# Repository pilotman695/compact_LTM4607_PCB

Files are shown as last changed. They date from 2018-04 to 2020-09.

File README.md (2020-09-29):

# compact_LTM4607_PCB
A compact, 98% efficient, non-isolated DC-DC converter board based around the LTM4607

Input: 4.5-36V

Output: 0.8-24V, 5A (boost mode), 10A (buck mode)

## Version 1
Stand-off mounting, solderable wire connections

## Version 2
Card-edge style, compacted

Assembly tutorial: [https://www.youtube.com/watch?v=_QmpLCoHiIg](https://www.youtube.com/watch?v=_QmpLCoHiIg)

## Carrier Board
3 card-edge connectors, hotswapping, reverse polarity protection, switchable output nodes, undervoltage/overvoltage lockout

Input: 12.5-36V

Output: 3.3-24V

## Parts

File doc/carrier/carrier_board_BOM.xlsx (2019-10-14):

Qty | Parts | Value | Device | Package | Description | Manufacturer Part Number | Datasheet | Unit Price | Total
5 | C1, C2, C3, C9, C10 | 100n | C-EUC0603 | C0603 | CAPACITOR, European symbol | CL10F104ZB8NNNC | http://www.samsungsem.com/global/front/downloadcms.do?fileName=C_CL10F104ZB8NNNC.pdf | $0.054 | $0.270
1 | C4 | 1n | C-EUC0402 | C0402 | CAPACITOR, European symbol | GCM155R71H102KA37D | http://psearch.en.murata.com/capacitor/product/GCM155R71H102KA37%23.pdf | $0.140 | $0.140
1 | C5 | 100n | C-EUC0402 | C0402 | CAPACITOR, European symbol | C1005X7R1H104K050BB | https://product.tdk.com/info/en/documents/chara_sheet/C1005X7R1H104K050BB.pdf | $0.180 | $0.180
1 | C6 | 100u | CPOL-USE5-10.5 | E5-10,5 | POLARIZED CAPACITOR, American symbol | EEU-FR1J101 | https://industrial.panasonic.com/cdbs/www-data/pdf/RDF0000/ABA0000C1022.pdf | $0.910 | $0.910
2 | C7, C8 | 100n | C-EUC0805 | C0805 | CAPACITOR, European symbol | CL21F104ZBCNNNC | http://www.samsungsem.com/kr/front/downloadcms.do?fileName=C_CL21F104ZBCNNNC.pdf | $0.140 | $0.280
2 | CON1, CON2 | SM03B-GHS-TB | SM03B-GHS-TB | SM03B-GHS-TB |  | SM03B-GHS-TB(LF)(SN) | http://www.jst-mfg.com/product/pdf/eng/eGH.pdf | $0.690 | $1.380
3 | D1, D2, D3 | 10 | BZT52C10-TP | SOD123 |  | BZT52C10-TP | http://www.mccsemi.com/up_pdf/BZT52C2V4~BZT52C43(500mW)(SOD-123).pdf | $0.310 | $0.930
2 | D4, D5 | SMBJ30CA | SMBJ30CA | DO214AA |  | SMBJ30CA | https://www.littelfuse.com/~/media/electronics/datasheets/tvs_diodes/littelfuse_tvs_diode_smbj_datasheet.pdf.pdf | $0.650 | $1.300
2 | D6, D7 | SD0603S040S0R2 | SD0603S040S0R2 | CHIPLED_0603 | DIODE SCHOTTKY 40V 200MA 0603 | SD0603S040S0R2 | http://datasheets.avx.com/schottky.pdf | $0.660 | $1.320
1 | D8 | MBRS2040LT3G | MBRS2040LT3G | DO214AA | DIODE SCHOTTKY 40V 2A SMB | MBRS2040LT3G | https://www.onsemi.com/pub/Collateral/MBRS2040LT3-D.PDF | $0.530 | $0.530
3 | F1, F2, F3 |  | FUSEHOLDER | 3557-10 |  | 3557-10 | http://www.keyelco.com/product-pdf.cfm?p=14224 | $1.360 | $4.080
3 | F1, F2, F3 | 15A | FUSE | Blade, Miniature (Low Profile) |  | 0891015.NXS | http://www.littelfuse.com/~/media/automotive/datasheets/fuses/passenger-car-and-commercial-vehicle/blade-fuses/littelfuse_lowprofilemini_datasheet.pdf | $0.520 | $1.560
2 | F4, F5 |  | 3557-10 | 3557-10 |  | 3557-10 | http://www.keyelco.com/product-pdf.cfm?p=14224 | $1.360 | $2.720
2 | F4, F5 | 30A | FUSEHOLDER | Blade, Miniature (Low Profile) |  | 0891030.NXS | http://www.littelfuse.com/~/media/automotive/datasheets/fuses/passenger-car-and-commercial-vehicle/blade-fuses/littelfuse_lowprofilemini_datasheet.pdf | $0.520 | $1.040
1 | F6 | 0.5 | FUSE | R1206 |  | ERB-RG0R50V | https://industrial.panasonic.com/cdbs/www-data/pdf/AFA0000/AFA0000C7.pdf | $0.780 | $0.780
1 | JP1 |  | PINHD-2X3 | 2X03 | PIN HEADER | PREC003DAAN-RC | https://s3.amazonaws.com/catalogspreads-pdf/PAGE110-111%20.100%20MALE%20HDR%20ST.pdf | $0.250 | $0.250
1 | JP2 |  | PINHD-2X4 | 2X04 | PIN HEADER | PREC004DAAN-RC | https://s3.amazonaws.com/catalogspreads-pdf/PAGE110-111%20.100%20MALE%20HDR%20ST.pdf | $0.270 | $0.270
1 | JP3 |  | PINHD-1X02_2.54-SMD-90Â° | 1X02SMD/90 | PIN HEADER | TSM-102-01-T-SH | http://suddendocs.samtec.com/catalog_english/tsm.pdf | $0.400 | $0.400
2 | LED1, LED2 |  | LEDCHIPLED_0603 | CHIPLED_0603 | LED | 150060VS55040 | https://katalog.we-online.de/pbs/datasheet/150060VS55040.pdf | $0.240 | $0.480
3 | Q1, Q2, Q3 | SQJ407EP | SQJ407EP | POWERPACK_SO8L_SINGLE |  | SQJ407EP-T1_GE3 | http://www.vishay.com/docs/62806/sqj407ep.pdf | $1.980 | $5.940
4 | Q4, Q5, Q6, Q7 | SI7145DP | SI7145DP | SO-8-POWERPACK |  | SI7145DP-T1-GE3 | http://www.vishay.com/docs/64814/si7145dp.pdf | $3.680 | $14.720
1 | Q8 | BSS123 | BSS123 | SOT23 |  | DMN6075S-7 | https://www.diodes.com/assets/Datasheets/DMN6075S.pdf | $0.610 | $0.610
8 | R1, R2, R7, R8, R13, R14, R35, R36 | 1k | R-US_R0603 | R0603 | RESISTOR, American symbol | RC0603FR-071KL | http://www.yageo.com/documents/recent/PYu-RC_Group_51_RoHS_L_9.pdf | $0.039 | $0.312
2 | R19, R22 | 4.12M | R-US_R0402 | R0402 | RESISTOR, American symbol | CRCW04024M12FKED | http://www.vishay.com/docs/20035/dcrcwe3.pdf | $0.066 | $0.132
2 | R20, R23 | 210k | R-US_R0402 | R0402 | RESISTOR, American symbol | RC0402FR-07232KL | http://www.yageo.com/documents/recent/PYu-RC_Group_51_RoHS_L_9.pdf | $0.027 | $0.054
2 | R21, R24 | 150k | R-US_R0402 | R0402 | RESISTOR, American symbol | RC0402FR-07124KL | http://www.yageo.com/documents/recent/PYu-RC_Group_51_RoHS_L_9.pdf | $0.027 | $0.054
1 | R26 | 255k | R-US_R0402 | R0402 | RESISTOR, American symbol | RC0402FR-07255KL | http://www.yageo.com/documents/recent/PYu-RC_Group_51_RoHS_L_9.pdf | $0.027 | $0.027
2 | R28, R29 | 10k | R-US_R1206 | R0805 | RESISTOR, American symbol | RC0805FR-0710KL | http://www.yageo.com/documents/recent/PYu-RC_Group_51_RoHS_L_9.pdf | $0.069 | $0.138
5 | R3, R9, R15, R25, R27 | 100k | R-US_R0603 | R0603 | RESISTOR, American symbol | AC0603FR-07100KL | http://www.yageo.com/NewPortal/yageodocoutput?fileName=/pdf/R-Chip/PYu-AC_51_RoHS_L_6.pdf | $0.048 | $0.240
2 | R30, R33 | 2k | R-US_R0603 | R0603 | RESISTOR, American symbol | RC0603FR-072KP | http://www.yageo.com/NewPortal/yageodocoutput?fileName=/pdf/R-Chip/PYu-RC_51_RoHS_P_0.pdf | $0.066 | $0.132
2 | R31, R32 | 220 | R-US_R0805 | R0805 | RESISTOR, American symbol | AC0805FR-07220RL | http://www.yageo.com/NewPortal/yageodocoutput?fileName=/pdf/R-Chip/PYu-AC_51_RoHS_L_6.pdf | $0.082 | $0.164
1 | R34 | 1k | R-US_R0805 | R0805 | RESISTOR, American symbol | RC0805FR-071KL | http://www.yageo.com/documents/recent/PYu-RC_Group_51_RoHS_L_9.pdf | $0.069 | $0.069
1 | R37 | 0 | R-US_R0805 | R0805 | RESISTOR, American symbol | RC0603JR-070RL | http://www.yageo.com/documents/recent/PYu-RC_Group_51_RoHS_L_9.pdf | $0.032 | $0.032
3 | R4, R10, R16 | 2.5m | R-US_R2512 | R2512 | RESISTOR, American symbol | TLR3A10KR0025FTDG | https://www.te.com/commerce/DocumentDelivery/DDEController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 | $1.400 | $4.200
4 | R5, R11, R17, R39 | 5k | R-US_R0603 | R0603 | RESISTOR, American symbol | RC0603FR-074K99L | http://www.yageo.com/documents/recent/PYu-RC_Group_51_RoHS_L_9.pdf | $0.039 | $0.156
4 | R6, R12, R18, R38 | 50k | R-US_R0603 | R0603 | RESISTOR, American symbol | RC0603FR-0749K9L | http://www.yageo.com/documents/recent/PYu-RC_Group_51_RoHS_L_9.pdf | $0.039 | $0.156
6 | U1, U3, U4, U6, U7, U9 | LTV-355T | LTV-355T | SMD4 |  | LTV-355T | http://optoelectronics.liteon.com/upload/download/DS70-2001-006/LTV-355T%20series%20201610.pdf | $0.770 | $4.620
1 | U10 | LTC4418 | LTC4418 | QFN20 |  | LTC4418CUF#PBF | http://www.analog.com/media/en/technical-documentation/data-sheets/ltc4418.pdf | $7.950 | $7.950
1 | U11 | TEENSY_3.1_BASIC_2 | TEENSY_3.1_BASIC_2 | TEENSY_3.1_BASIC_2 | Footprint for Teensy 3.1 board using all pin connections on the outer perimeter | 2756 | https://media.digikey.com/pdf/Data%20Sheets/Adafruit%20PDFs/2756_Web.pdf | $34.930 | $34.930
2 |  |  |  |  | Headers for Teensy | PPTC141LFBN-RC | https://drawings-pdf.s3.amazonaws.com/10492.pdf | $1.270 | $2.540
1 | U12 | MCP2562 | MCP2562 | SO-8 |  | MCP2562T-E/SN | http://www.microchip.com/mymicrochip/filehandler.aspx?ddocname=en561044 | $1.390 | $1.390
1 | U13 | VX7805-500 | 0.1"_LINEAR_REGULATOR_REPLACEMENT | 0.1"_LINEAR_REGULATOR_REPLACEMENT |  | VX7805-500 | https://www.cui.com/product/resource/digikeypdf/vx78-500.pdf | $3.940 | $3.940
3 | U2, U5, U8 |  | INA226 | MSOP10 |  | INA226AIDGSR | http://www.ti.com/lit/ds/symlink/ina226.pdf | $4.300 | $12.900
2 | V1, V2 |  | MKDSD_1730502 | MKDSD_1730502 |  | 1730502 | https://www.phoenixcontact.com/online/portal/us?uri=pxc-oc-itemdetail:pid=1730502&library=usen&tab=1 | $2.790 | $5.580
3 | X1, X3, X5 |  | 284391-6 | 284391-6 |  | 284391-6 | https://www.te.com/commerce/DocumentDelivery/DDEController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 | $4.770 | $14.310
3 | X2, X4, X6 |  | 1926155-2_SOCK | 1926155-2_SOCK |  | 1926155-2 | https://www.te.com/commerce/DocumentDelivery/DDEController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 | $18.310 | $54.930
 |  |  |  |  |  | Total (component value only) |  |  | $189.05

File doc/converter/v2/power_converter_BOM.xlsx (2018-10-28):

Qty | Value | Device | Package | Parts | Description | Manufacturer Part Number | Datasheet | Unit Price | Total
1 | 5n | C-EUC0603 | C0603 | C16 | CAPACITOR, European symbol | C0603C512J5JAC7867 | https://api.kemet.com/component-edge/download/datasheet/C0603C512J5JAC7867.pdf | $0.69 | $0.69
5 | 10u | C-EUC1210 | C1210 | C2, C4, C5, C8, C9 | CAPACITOR, European symbol | C3225X5R1H106M250AB | https://product.tdk.com/info/en/documents/chara_sheet/C3225X5R1H106M250AB.pdf | $2.30 | $11.50
2 | 220u | PCR1V221MCL1GS | PCR1V221MCL1GS | C3, C14 |  | PCR1V221MCL1GS | http://nichicon-us.com/english/products/pdfs/e-pcr.pdf | $4.47 | $8.94
1 | 180u | PCR1H181MCL1GS | PCR1H181MCL1GS | C7 |  | PCR1H181MCL1GS | http://nichicon-us.com/english/products/pdfs/e-pcr.pdf | $5.35 | $5.35
1 | 4.7V | ZENER-DIODESOD80C | SOD80C | D1 | Z-Diode | BZT55C4V7-GS08 | http://www.vishay.com/docs/85637/bzt55-se.pdf | $0.28 | $0.28
1 | 20A | 501_FUSE | R1206 | F1 |  | 3413.0330.22 | https://us.schurter.com/pdf/english/typ_UST_1206.pdf | $0.71 | $0.71
1 | 4.7u | PA4343.472ANLT | PA4343.472ANLT | L1 |  | PA4343.472ANLT | http://products.pulseelex.com/files/product_files/P793_782.pdf | $3.19 | $3.19
1 | 51k | R-US_R0603 | R0603 | R1 | RESISTOR, American symbol | ERJ-3EKF5102V | https://industrial.panasonic.com/cdbs/www-data/pdf/RDA0000/AOA0000C304.pdf | $0.15 | $0.15
1 | 8.5k | R-US_R0603 | R0603 | R3 | RESISTOR, American symbol | ERJ-3EKF8451V | https://industrial.panasonic.com/cdbs/www-data/pdf/RDA0000/AOA0000C304.pdf | $0.15 | $0.15
2 | 15m | R-US_R1206 | R1206 | R4, R5 | RESISTOR, American symbol | ERJ-8BWFR015V | https://industrial.panasonic.com/cdbs/www-data/pdf/RDN0000/AOA0000C313.pdf | $1.10 | $2.20
1 | 4.7k | R-US_R0603 | R0603 | R6 | RESISTOR, American symbol | RC0603FR-074K7L | http://www.yageo.com/documents/recent/PYu-RC_Group_51_RoHS_L_9.pdf | $0.04 | $0.04
1 | 150 | R-US_R0603 | R0603 | R7 | RESISTOR, American symbol | ERA-3AEB151V | https://industrial.panasonic.com/cdbs/www-data/pdf/RDM0000/AOA0000C307.pdf | $0.52 | $0.52
1 | 6.98k | R-US_R0603 | R0603 | R8 | RESISTOR, American symbol | ERA-3AEB6981V | https://industrial.panasonic.com/cdbs/www-data/pdf/RDM0000/AOA0000C307.pdf | $0.52 | $0.52
1 | 2.7k | R-US_R0603 | R0603 | R9 | RESISTOR, American symbol | ERJ-3EKF2701V | https://industrial.panasonic.com/cdbs/www-data/pdf/RDA0000/AOA0000C304.pdf | $0.15 | $0.15
1 |  | LTM4607EVPBF | LGA-141 | U1 |  | LTM4607EV#PBF | http://www.linear.com/docs/25661 | $56.02 | $56.02
 |  |  |  |  |  |  |  | Grand Total: | $90.41

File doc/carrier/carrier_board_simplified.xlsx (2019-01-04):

Qty | Value | Parts | Device | Package | Description | Manufacturer Part Number | Datasheet | Unit Price | Total
4 | 100n | C1, C2, C3, C4 | C-EUC0603 | C0603 | CAPACITOR, European symbol | CL10B104KB8NNNC | http://www.samsungsem.com/kr/support/product-search/mlcc/__icsFiles/afieldfile/2018/08/29/Data%20sheet_CL10B104KB8NNNC.pdf | $0.05 | $0.20
3 | 10 | D1, D2, D3 | BZT52C10-TP | SOD123 |  | BZT52C10-TP | http://www.mccsemi.com/up_pdf/BZT52C2V4~BZT52C43(500mW)(SOD-123).pdf | $0.32 | $0.96
1 | 30A | F1 | 3557-10 | 3557-10 |  | 3557-10 | http://www.keyelco.com/product-pdf.cfm?p=14224 | $1.43 | $1.43
1 | 30A | F1 | FUSEHOLDER | Blade, Miniature (Low Profile) |  | 0891030.NXS | http://www.littelfuse.com/~/media/automotive/datasheets/fuses/passenger-car-and-commercial-vehicle/blade-fuses/littelfuse_lowprofilemini_datasheet.pdf | $0.520 | $0.520
1 | 0.5 | F2 | 501_FUSE | R1206 |  | ERB-RG0R50V | https://industrial.panasonic.com/cdbs/www-data/pdf/AFA0000/AFA0000C7.pdf | $0.780 | $0.78
1 |  | JP1 | PINHD-1X02_2.54-SMD-90Â° | 1X02SMD/90 | PIN HEADER | TSM-102-01-T-SH | http://suddendocs.samtec.com/catalog_english/tsm.pdf | $0.400 | $0.40
1 |  | JP2 | PINHD-1X03_2.54-SMD-90Â° | 1X03SMD/90 | PIN HEADER | TSM-103-01-T-SH | http://suddendocs.samtec.com/catalog_english/tsm.pdf | $0.63 | $0.63
3 | SQJ407EP | Q1, Q2, Q3 | SQJ407EP | POWERPAK_SO8L_SINGLE |  | SQJ407EP-T1_GE3 | http://www.vishay.com/docs/62806/sqj407ep.pdf | $2.290 | $6.87
6 | 1k | R1, R2, R5, R6, R9, R10 | R-US_R0603 | R0603 | RESISTOR, American symbol | RC0603FR-071KL | http://www.yageo.com/documents/recent/PYu-RC_Group_51_RoHS_L_9.pdf | $0.039 | $0.23
3 | 100k | R3, R7, R11 | R-US_R0603 | R0603 | RESISTOR, American symbol | AC0603FR-07100KL | http://www.yageo.com/NewPortal/yageodocoutput?fileName=/pdf/R-Chip/PYu-AC_51_RoHS_L_6.pdf | $0.048 | $0.14
3 | 2.5m | R4, R8, R12 | R-US_R2512 | R2512 | RESISTOR, American symbol | TLR3A10KR0025FTDG | https://www.te.com/commerce/DocumentDelivery/DDEController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 | $1.470 | $4.41
3 | LTV-355T | U1, U3, U5 | LTV-355T | SMD4 |  | LTV-355T | http://optoelectronics.liteon.com/upload/download/DS70-2001-006/LTV-355T%20series%20201610.pdf | $0.810 | $2.43
3 |  | U2, U4, U6 | INA226 | MSOP10 |  | INA226AIDGSR | http://www.ti.com/lit/ds/symlink/ina226.pdf | $4.510 | $13.53
1 | LM340MPX-5.0/NOPB | U7 | LM340S | SOT223 | 3-Terminal Positive Regulators | LM340MPX-5.0/NOPB | http://www.ti.com/lit/ds/symlink/lm340.pdf | $2.13 | $2.13
3 |  | X1, X4, X6 | 284391-6 | 284391-6 |  | 284391-6 | https://www.te.com/commerce/DocumentDelivery/DDEController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 | $4.960 | $14.88
3 |  | X2, X5, X7 | 1926155-2_SOCK | 1926155-2_SOCK |  | 1926155-2 | https://www.te.com/commerce/DocumentDelivery/DDEController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 | $19.220 | $57.66
1 |  | X3 | OSTT7020150 | OSTT7020150 |  | OSTT7020150 | http://www.on-shore.com/wp-content/uploads/2015/09/OSTT7XX0150.pdf | $2.18 | $2.18
 |  |  |  |  |  |  |  | Grand Total: | $109.39

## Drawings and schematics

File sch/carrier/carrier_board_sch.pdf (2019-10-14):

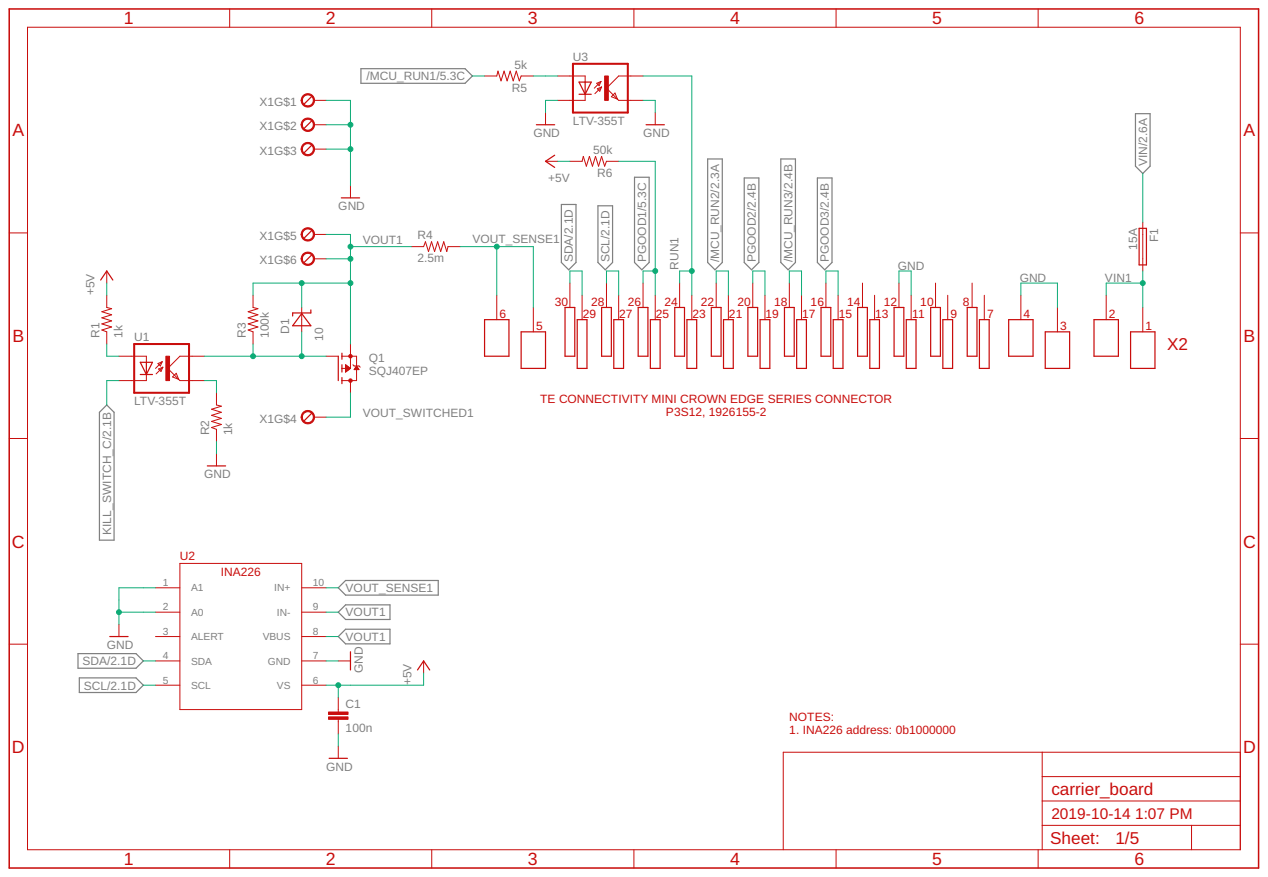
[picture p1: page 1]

TE CONNECTIVITY MINI CROWN EDGE SERIES CONNECTOR

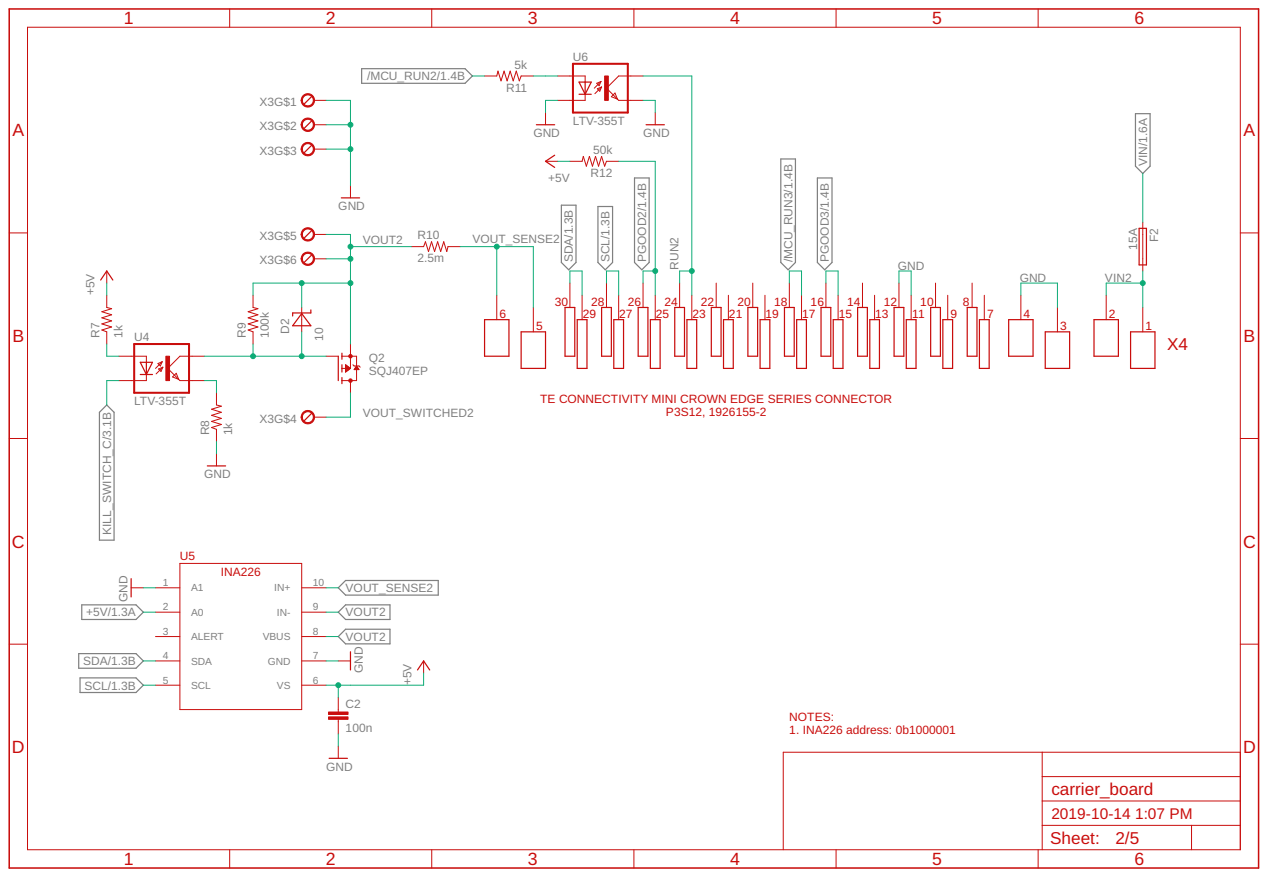
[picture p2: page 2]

TE CONNECTIVITY MINI CROWN EDGE SERIES CONNECTOR

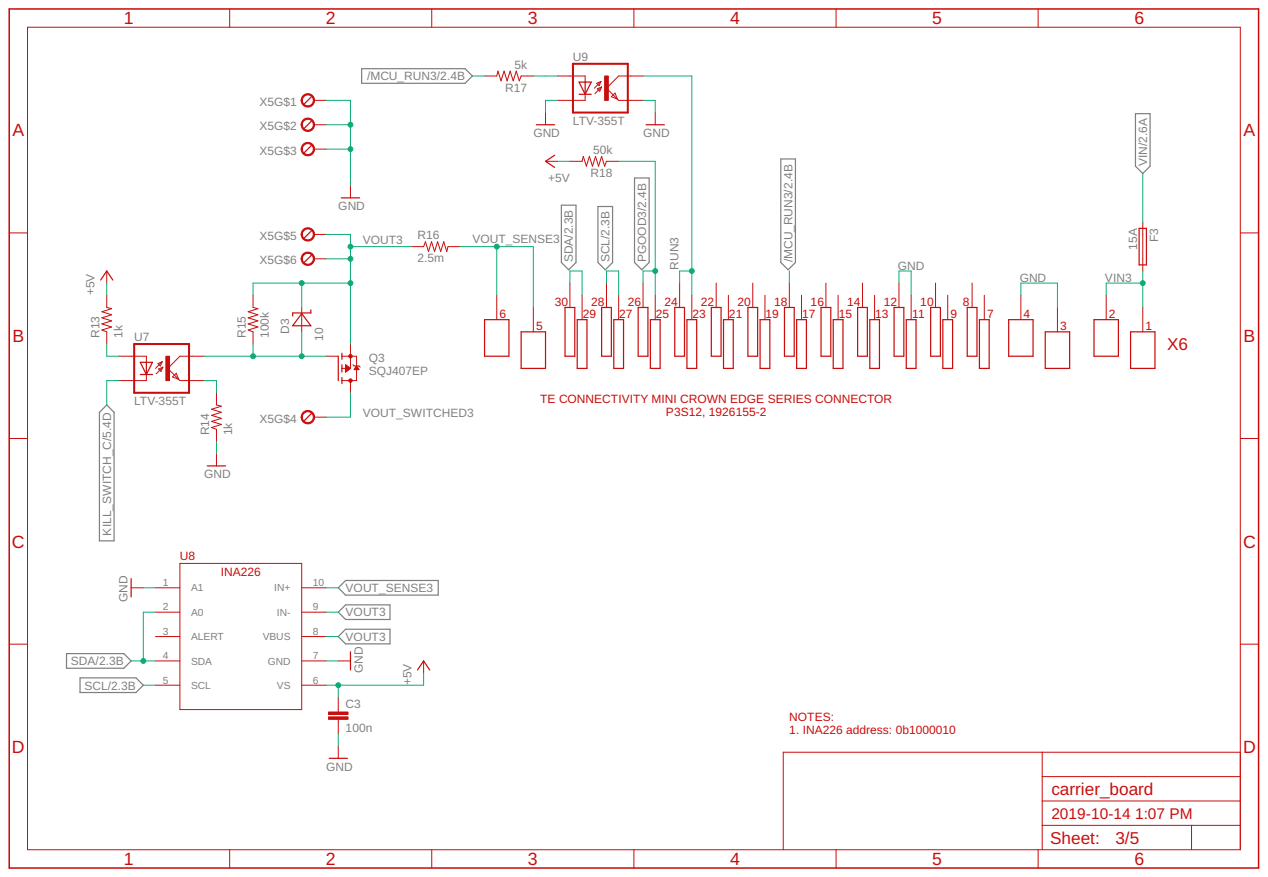
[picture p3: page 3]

TE CONNECTIVITY MINI CROWN EDGE SERIES CONNECTOR

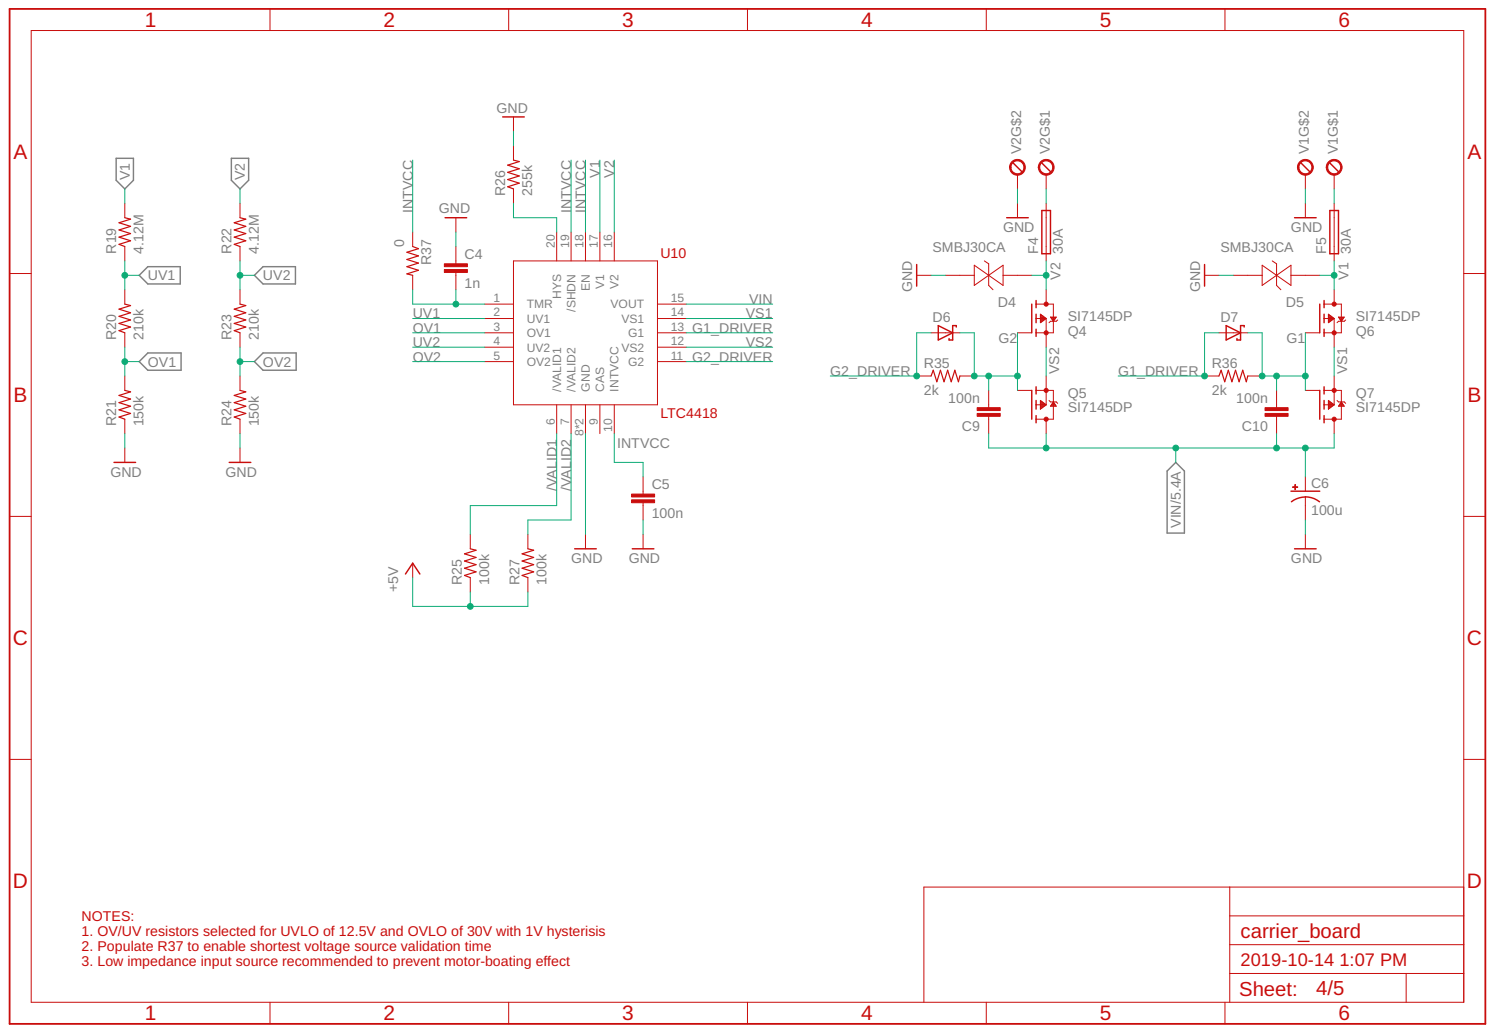
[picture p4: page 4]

NOTES: 1. OV/UV resistors selected for UVLO of 12.5V and OVLO of 30V with 1V hysterisis 2. Populate R37 to enable shortest voltage source validation time

3. Low impedance input source recommended to prevent motor-boating effect

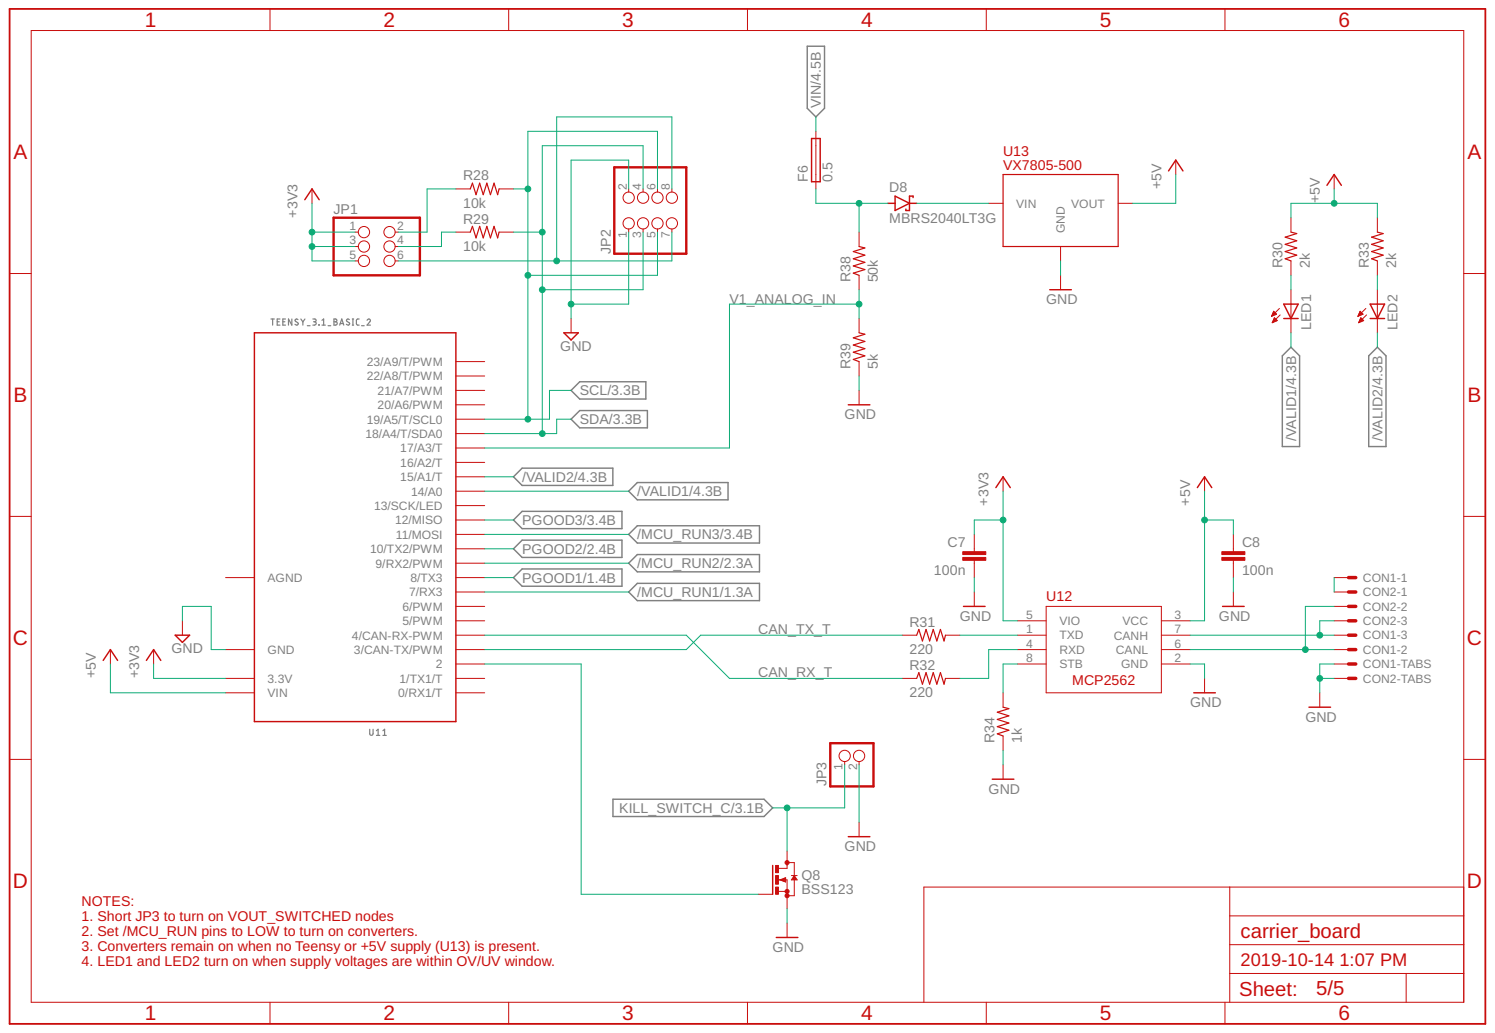
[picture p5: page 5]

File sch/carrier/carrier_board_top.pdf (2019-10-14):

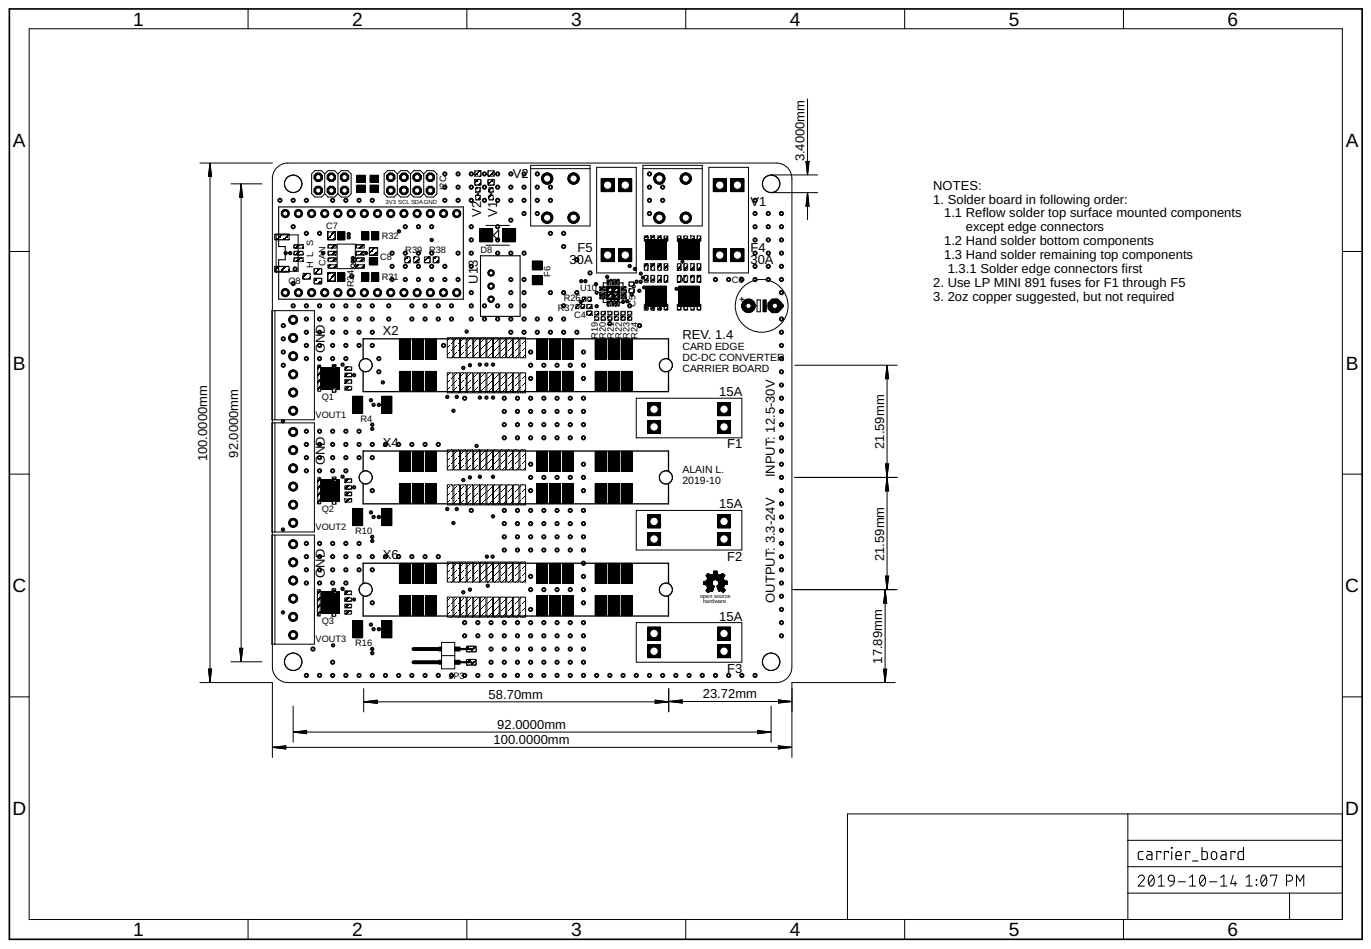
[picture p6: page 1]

V1V2 CARD EDGE DC-DC CONVERTER CARRIER BOARD ALAIN L. 2019-10 VOUT3 VOUT2 VOUT1 GND GND GND INPUT: 12.5-30V OUTPUT: 3.3-24V X REV. 1.4 2X4X6 V1 V2 F5 30A F4 30A F1 15AF2 15AF3 15A U13 3V3 SCL SDAGND I2C H L CANS R4 Q1 R10 Q2 R16 Q3 R31 R32 C7 C8 R34 U10 C4 R26 C5 R19 R20 R21 R22 R23 R24 C6 JP3 F6 Q8 R37 R39 R38 D8 open source hardware 100.0000mm 100.0000mm 92.0000mm 92.0000mm 3.4000mm 17.89mm 21.59mm 21.59mm 58.70mm 23.72mm NOTES: 1. Solder board in following order: 1.1 Reflow solder top surface mounted components except edge connectors 1.2 Hand solder bottom components 1.3 Hand solder remaining top components 1.3.1 Solder edge connectors first 2. Use LP MINI 891 fuses for F1 through F5 3. 2oz copper suggested, but not required ABCD 1 2 3 4 5 6 ABCD 1 2 3 4 5 6

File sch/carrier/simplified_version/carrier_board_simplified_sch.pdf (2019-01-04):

A

A

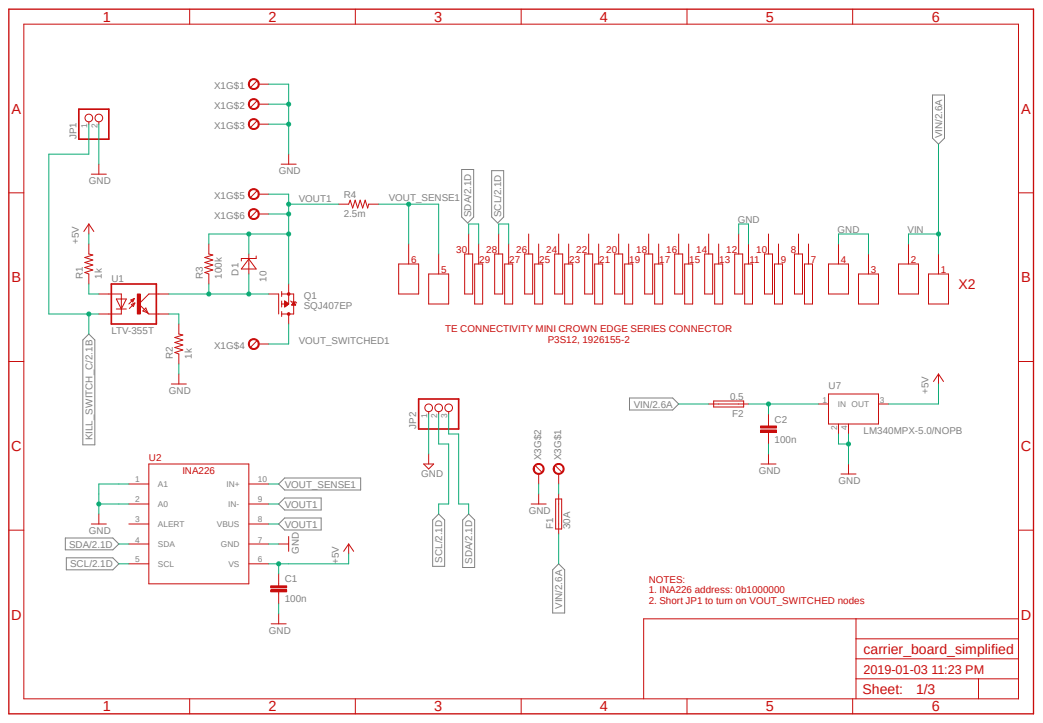
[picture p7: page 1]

TE CONNECTIVITY MINI CROWN EDGE SERIES CONNECTOR

1. INA226 address: 0b1000000
2. Short JP1 to turn on VOUT_SWITCHED nodes

A

A

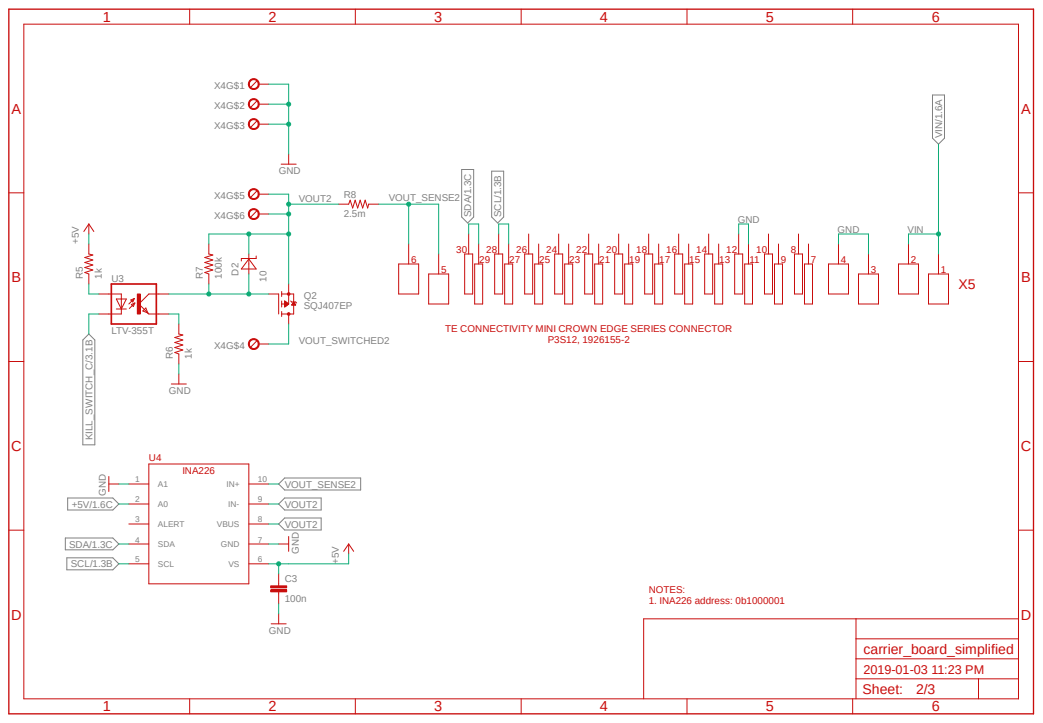
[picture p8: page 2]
GND; SQJ407EP; LTV-355T; ALERT 3; SDA 4; SCL 5; 6 GND; 7 VBUS; VOUT_SENSE2; VOUT2; SDA/1.3C; SCL/1.3B; VOUT_SWITCHED2 KILL_SWITCH_C/3.1B; VIN/1.6A; VIN; NOTES: 1. INA226 address: 0b1000001; Sheet:; carrier_board_simplified; INA226

TE CONNECTIVITY MINI CROWN EDGE SERIES CONNECTOR

GND GND GND

A

A

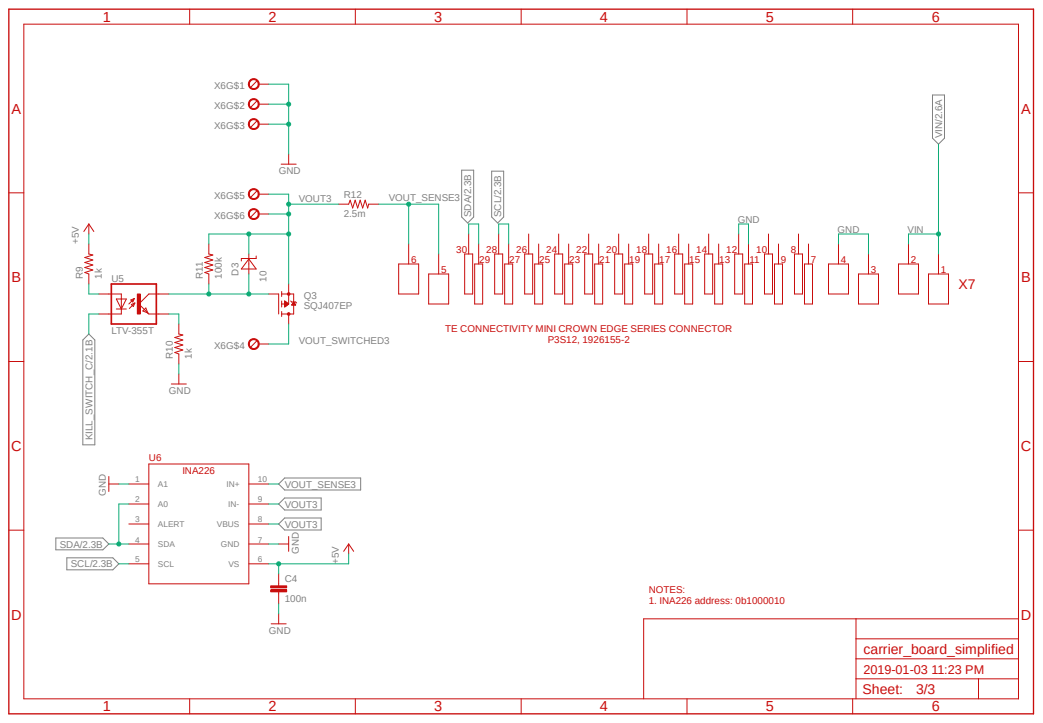
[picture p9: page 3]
GND; SQJ407EP; LTV-355T; ALERT 3; SDA 4; SCL 5; 6 GND; 7 VBUS; R¹¹; D³ R¹⁰ R⁹; VOUT_SENSE3; VOUT3; SDA/2.3B; SCL/2.3B; VOUT_SWITCHED3 KILL_SWITCH_C/2.1B; VIN/2.6A; VIN; NOTES: 1. INA226 address: 0b1000010; Sheet:; carrier_board_simplified; INA226

TE CONNECTIVITY MINI CROWN EDGE SERIES CONNECTOR

GND GND GND

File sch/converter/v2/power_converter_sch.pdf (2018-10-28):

A

A

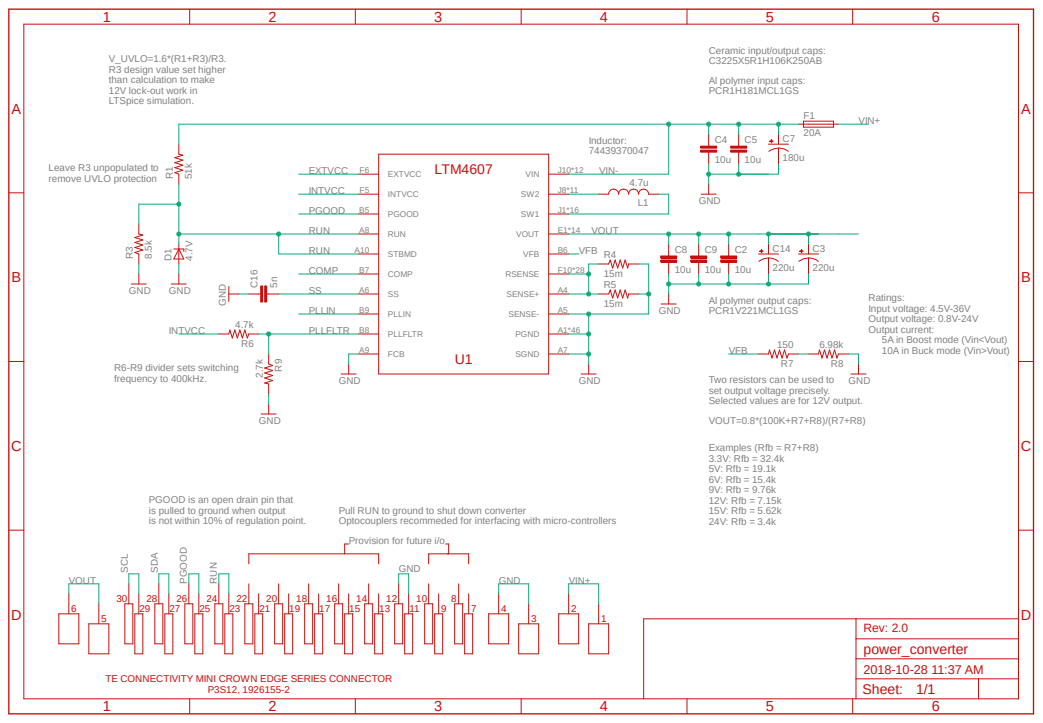
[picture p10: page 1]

V_UVLO=1.6*(R1+R3)/R3.
R3 design value set higher
than calculation to make
12V lock-out work in
LTSpice simulation.

Ceramic input/output caps:
Al polymer input caps:
PCR1H181MCL1GS

Al polymer output caps:
PCR1V221MCL1GS

Ratings:
Input voltage: 4.5V-36V
Output voltage: 0.8V-24V
Output current:
5A in Boost mode (Vin<Vout)
10A in Buck mode (Vin>Vout)

Two resistors can be used to
set output voltage precisely.
Selected values are for 12V output.
VOUT=0.8*(100K+R7+R8)/(R7+R8)

PGOOD is an open drain pin that
is pulled to ground when output
is not within 10% of regulation point.

Pull RUN to ground to shut down converter
Optocouplers recommeded for interfacing with micro-controllers
Provision for future i/o

TE CONNECTIVITY MINI CROWN EDGE SERIES CONNECTOR

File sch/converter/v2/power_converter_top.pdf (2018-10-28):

A

A

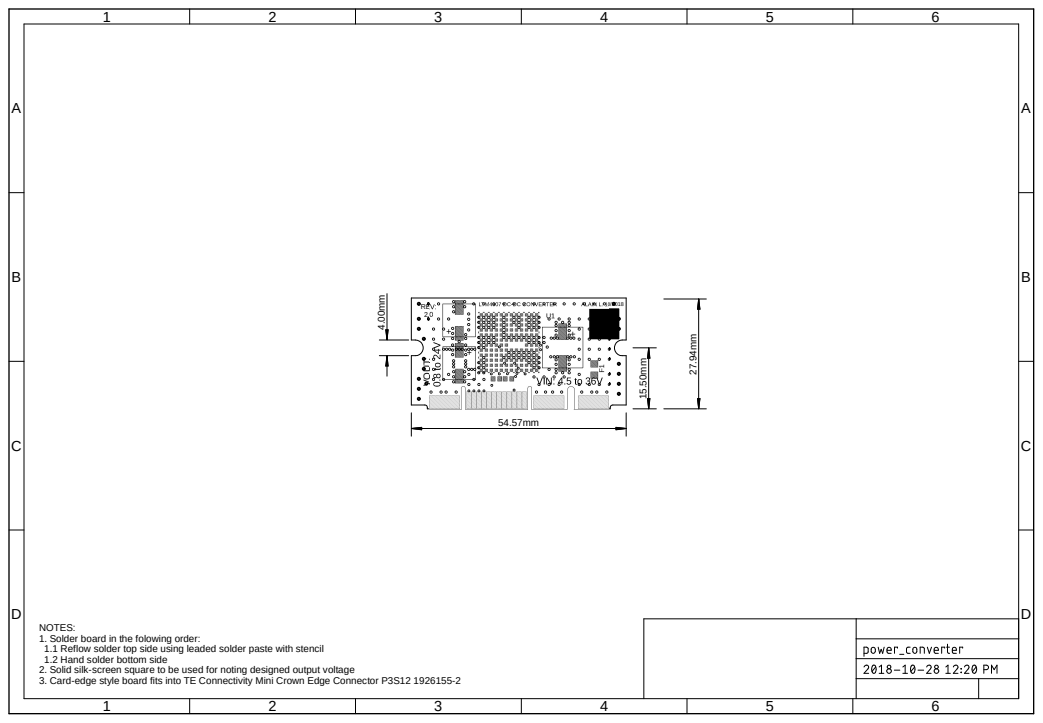
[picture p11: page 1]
VOUT: REV: 2.0 27.94mm

NOTES:
1. Solder board in the folowing order:
1.1 Reflow solder top side using leaded solder paste with stencil
1.2 Hand solder bottom side
2. Solid silk-screen square to be used for noting designed output voltage
3. Card-edge style board fits into TE Connectivity Mini Crown Edge Connector P3S12 1926155-2

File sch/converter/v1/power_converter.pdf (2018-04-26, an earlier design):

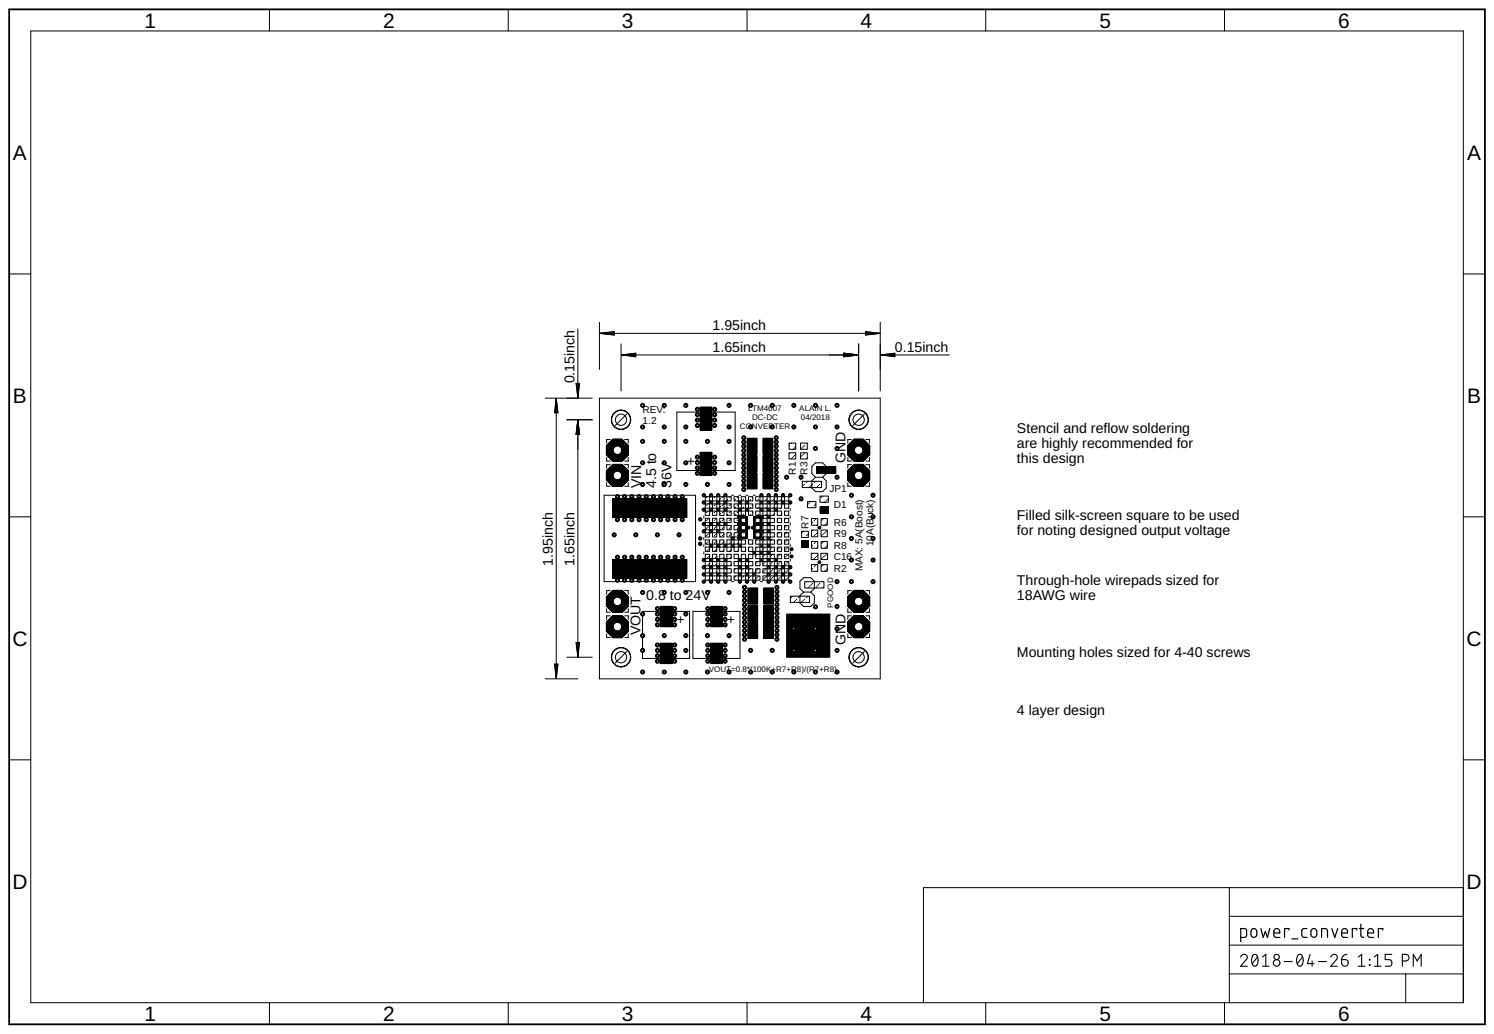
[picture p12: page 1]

Stencil and reflow soldering
are highly recommended for
this design Filled silk-screen square to be used

MAX: 5A(Boost) 10A(Buck) PGOOD

for noting designed output voltage Through-hole wirepads sized for 18AWG wire Mounting holes sized for 4-40 screws 4 layer design

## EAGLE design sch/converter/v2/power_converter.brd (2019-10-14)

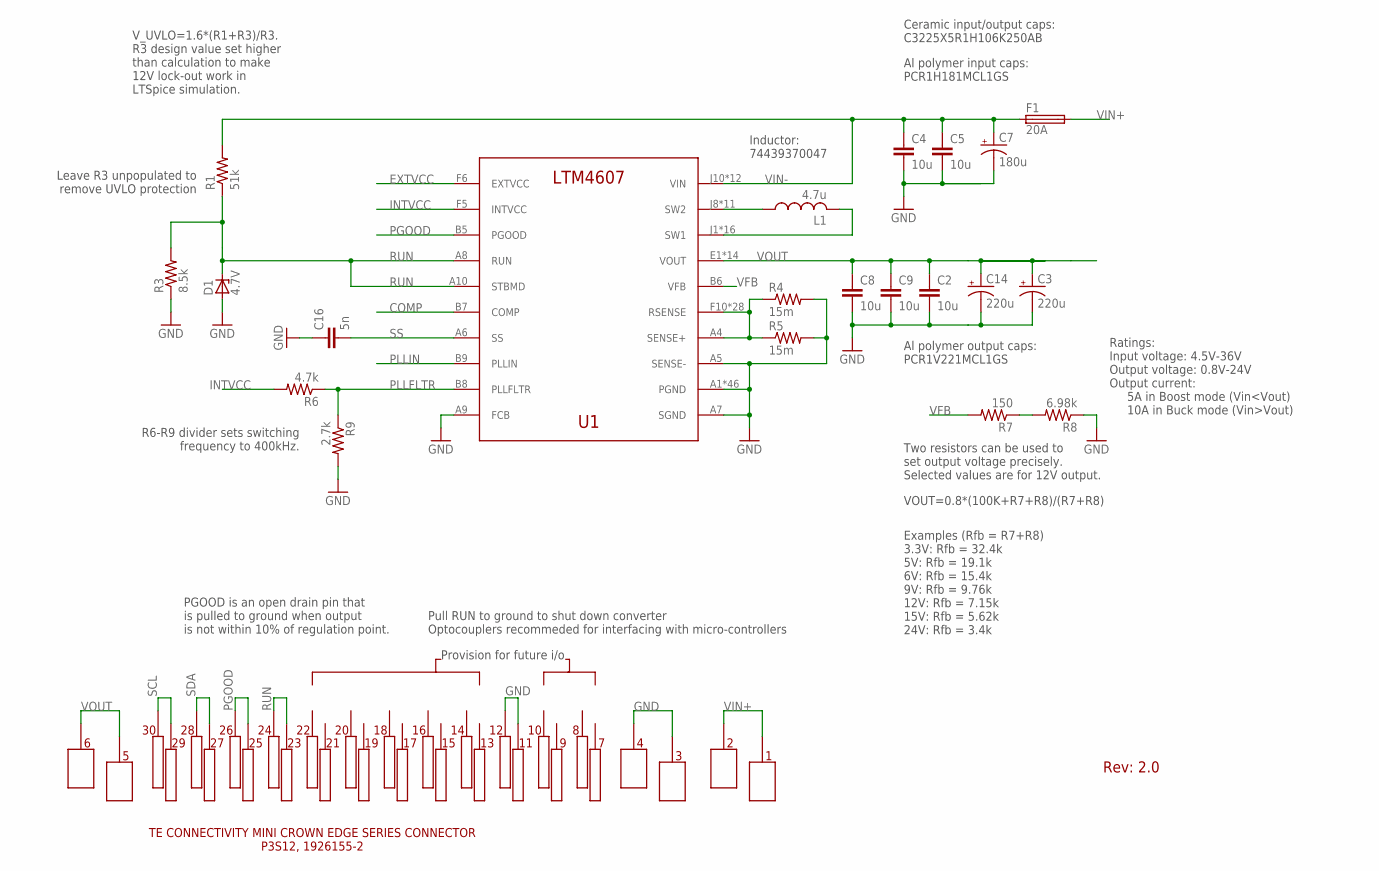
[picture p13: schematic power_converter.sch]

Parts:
C2, C4, C5, C8, C9: 10u; C1210
C3, C14: 220u; PCR1V221MCL1GS
C7: 180u; PCR1H181MCL1GS
C16: 5n; C0603
D1: 4.7V; SOD80C
F1: 20A; R1206
L1: 4.7u; PA4343.472ANLT
R1: 51k; R0603
R3: 8.5k; R0603
R4, R5: 15m; R1206
R6: 4.7k; R0603
R7: 150; R0603
R8: 6.98k; R0603
R9: 2.7k; R0603
U1: LTM4607EVPBF; LGA-141
U$1: 1926155-2_CARD

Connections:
COMP: U1.B7 (COMP)
EXTVCC: U1.F6 (EXTVCC)
GND: C2.2, C3.NEG (-), C4.2, C5.2, C7.NEG (-), C8.2, C9.2, C14.NEG (-), C16.1, D1.A, R3.1, R4.2, R5.2, R8.1, R9.2, U1.A1 (PGND), U1.A2 (PGND), U1.A3 (PGND), U1.A5 (SENSE-), U1.A7 (SGND), U1.A9 (FCB), U1.A11 (PGND), U1.A12 (PGND), U1.B1 (PGND), U1.B2 (PGND), U1.B3 (PGND), U1.B4 (PGND), U1.B10 (PGND), U1.B11 (PGND), U1.B12 (PGND), U1.C1 (PGND), U1.C2 (PGND), U1.C3 (PGND), U1.C4 (PGND), U1.C5 (PGND), U1.C6 (PGND), U1.C7 (PGND), U1.C8 (PGND), U1.C9 (PGND), U1.C10 (PGND), U1.C11 (PGND), U1.C12 (PGND), U1.D1 (PGND), U1.D2 (PGND), U1.D3 (PGND), U1.D4 (PGND), U1.D5 (PGND), U1.D6 (PGND), U1.D7 (PGND), U1.D8 (PGND), U1.D9 (PGND), U1.D10 (PGND), U1.D11 (PGND), U1.D12 (PGND), U1.E3 (PGND), U1.E4 (PGND), U1.E5 (PGND), U1.E6 (PGND), U1.E7 (PGND), U1.E8 (PGND), U1.E9 (PGND), U1.E10 (PGND), U1.E11 (PGND), U1.E12 (PGND), U$1.P$3, U$1.P$4, U$1.P$11, U$1.P$12
INTVCC: R6.2, U1.F5 (INTVCC)
unnamed: R7.1, R8.2
PGOOD: U1.B5 (PGOOD), U$1.P$25, U$1.P$26
PLLFLTR: R6.1, R9.1, U1.B8 (PLLFLTR)
PLLIN: U1.B9 (PLLIN)
RSENSE: R4.1, R5.1, U1.A4 (SENSE+), U1.F10 (RSENSE), U1.F11 (RSENSE), U1.F12 (RSENSE), U1.G5 (RSENSE), U1.G6 (RSENSE), U1.G7 (RSENSE), U1.G8 (RSENSE), U1.G9 (RSENSE), U1.G10 (RSENSE), U1.G11 (RSENSE), U1.G12 (RSENSE), U1.H5 (RSENSE), U1.H6 (RSENSE), U1.H7 (RSENSE), U1.H8 (RSENSE), U1.H9 (RSENSE), U1.H10 (RSENSE), U1.H11 (RSENSE), U1.H12 (RSENSE), U1.J5 (RSENSE), U1.J6 (RSENSE), U1.J7 (RSENSE), U1.K5 (RSENSE), U1.K6 (RSENSE), U1.L5 (RSENSE), U1.L6 (RSENSE), U1.M5 (RSENSE), U1.M6 (RSENSE)
RUN: D1.C, R1.1, R3.2, U1.A8 (RUN), U1.A10 (STBMD), U$1.P$23, U$1.P$24
SCL: U$1.P$29, U$1.P$30
SDA: U$1.P$27, U$1.P$28
SS: C16.2, U1.A6 (SS)
SW1: L1.P$2 (2), U1.J1 (SW1), U1.J2 (SW1), U1.J3 (SW1), U1.J4 (SW1), U1.K1 (SW1), U1.K2 (SW1), U1.K3 (SW1), U1.K4 (SW1), U1.L1 (SW1), U1.L2 (SW1), U1.L3 (SW1), U1.L4 (SW1), U1.M1 (SW1), U1.M2 (SW1), U1.M3 (SW1), U1.M4 (SW1)
SW2: L1.P$1 (1), U1.J8 (SW2), U1.J9 (SW2), U1.K7 (SW2), U1.K8 (SW2), U1.K9 (SW2), U1.L7 (SW2), U1.L8 (SW2), U1.L9 (SW2), U1.M7 (SW2), U1.M8 (SW2), U1.M9 (SW2)
VFB: R7.2, U1.B6 (VFB)
VIN+: F1.2, U$1.P$1, U$1.P$2
VIN-: C4.1, C5.1, C7.POS (+), F1.1, R1.2, U1.J10 (VIN), U1.J11 (VIN), U1.J12 (VIN), U1.K10 (VIN), U1.K11 (VIN), U1.K12 (VIN), U1.L10 (VIN), U1.L11 (VIN), U1.L12 (VIN), U1.M10 (VIN), U1.M11 (VIN), U1.M12 (VIN)
VOUT: C2.1, C3.POS (+), C8.1, C9.1, C14.POS (+), U1.E1 (VOUT), U1.E2 (VOUT), U1.F1 (VOUT), U1.F2 (VOUT), U1.F3 (VOUT), U1.F4 (VOUT), U1.G1 (VOUT), U1.G2 (VOUT), U1.G3 (VOUT), U1.G4 (VOUT), U1.H1 (VOUT), U1.H2 (VOUT), U1.H3 (VOUT), U1.H4 (VOUT), U$1.P$5, U$1.P$6

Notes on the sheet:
Ceramic input/output caps: C3225X5R1H106K250AB
Al polymer input caps: PCR1H181MCL1GS
Al polymer output caps: PCR1V221MCL1GS
Two resistors can be used to set output voltage precisely. Selected values are for 12V output.
VOUT=0.8*(100K+R7+R8)/(R7+R8)
V_UVLO=1.6*(R1+R3)/R3. R3 design value set higher than calculation to make 12V lock-out work in LTSpice simulation.
Leave R3 unpopulated to remove UVLO protection
R6-R9 divider sets switching frequency to 400kHz.
PGOOD is an open drain pin that is pulled to ground when output is not within 10% of regulation point.
Examples (Rfb = R7+R8) 3.3V: Rfb = 32.4k 5V: Rfb = 19.1k 6V: Rfb = 15.4k 9V: Rfb = 9.76k 12V: Rfb = 7.15k 15V: Rfb = 5.62k 24V: Rfb = 3.4k
Ratings: Input voltage: 4.5V-36V Output voltage: 0.8V-24V Output current: 5A in Boost mode (Vin<Vout) 10A in Buck mode (Vin>Vout)
Pull RUN to ground to shut down converter Optocouplers recommeded for interfacing with micro-controllers
Inductor: 74439370047
Rev: 2.0
Provision for future i/o

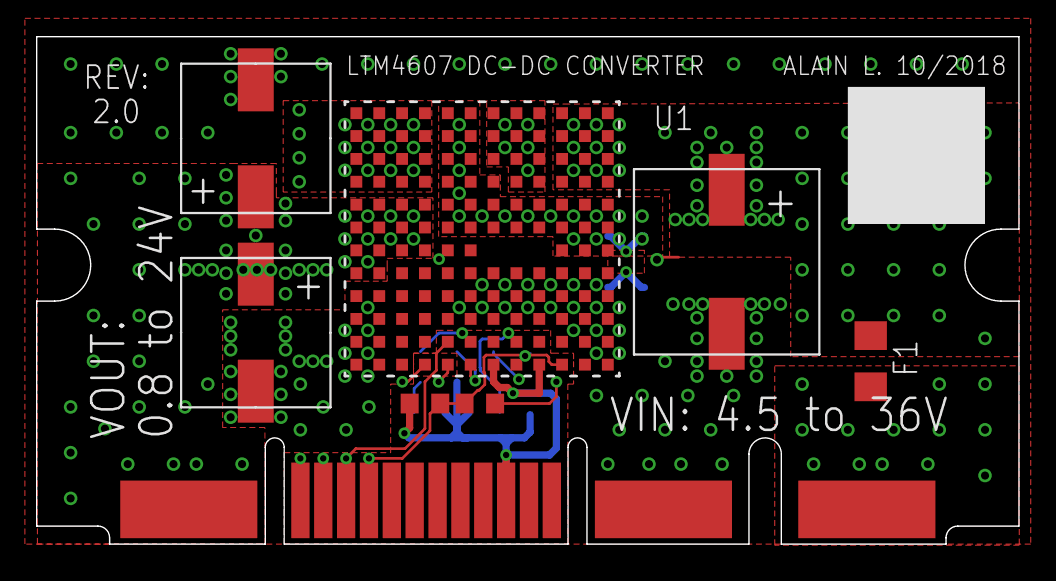
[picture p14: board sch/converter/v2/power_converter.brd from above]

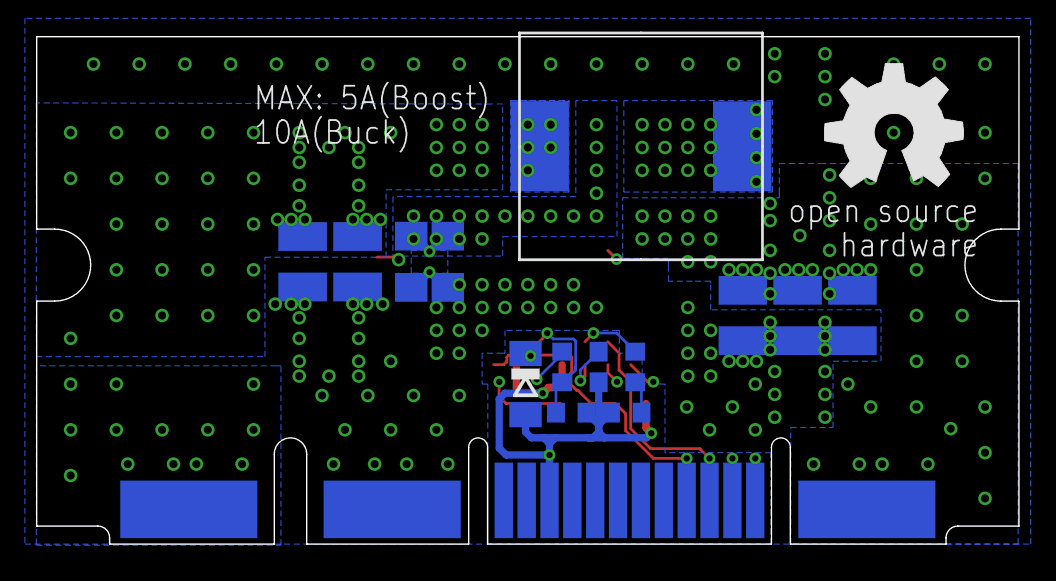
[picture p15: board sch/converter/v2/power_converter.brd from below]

Board: 4 copper layers, 54.6 x 28.2 mm, 24 parts (15 on the bottom side), 16 nets.

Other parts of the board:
U$2: OSHW_8MM
U$5: A4L-LOC

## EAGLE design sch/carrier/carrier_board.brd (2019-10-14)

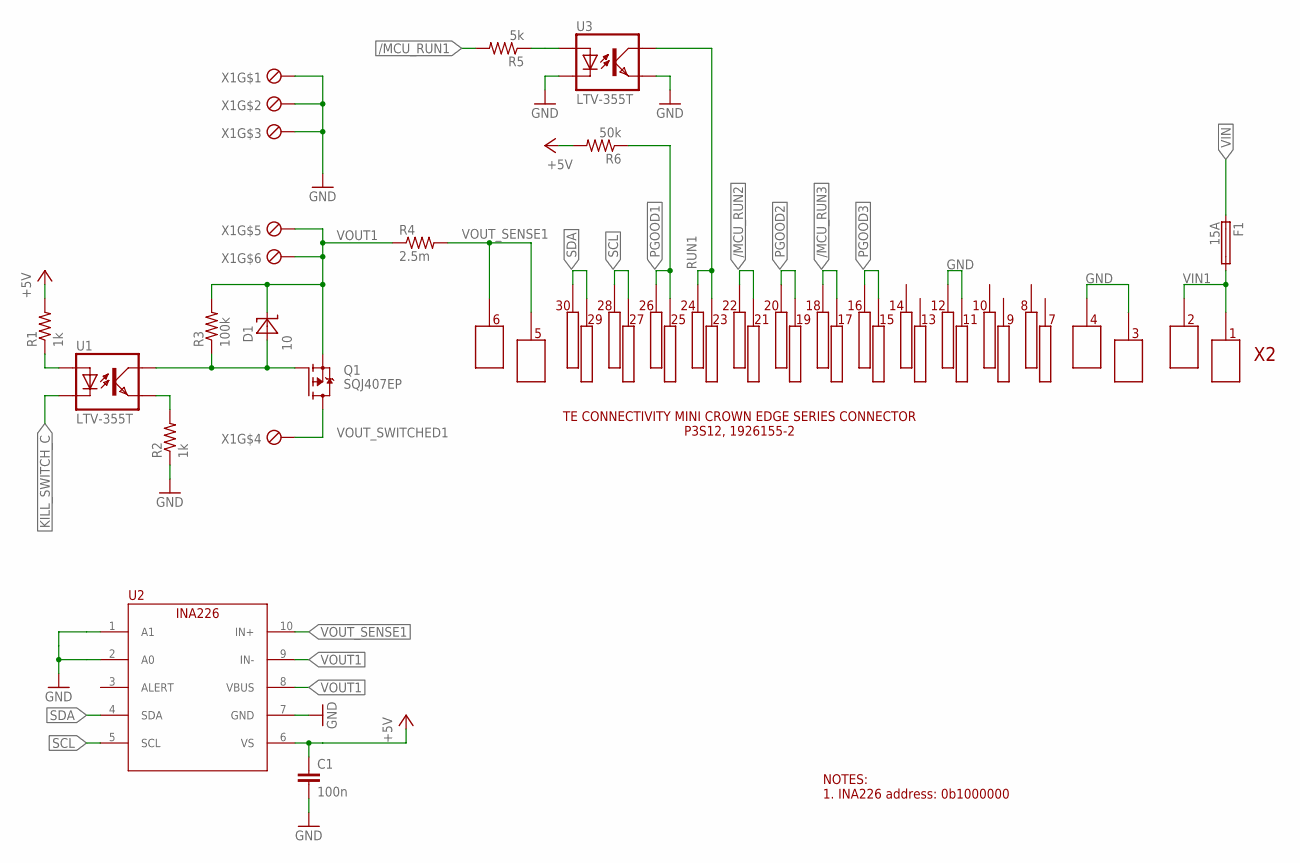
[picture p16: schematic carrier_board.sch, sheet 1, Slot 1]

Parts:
C1: 100n; C0603
D1: 10; SOD123
F1: 15A; 3557-10
Q1: SQJ407EP; POWERPAK_SO8L_SINGLE
R1, R2: 1k; R0603
R3: 100k; R0603
R4: 2.5m; R2512
R5: 5k; R0603
R6: 50k; R0603
U1, U3: LTV-355T; SMD4
U2: INA226; MSOP10
X1: 284391-6
X2: 1926155-2_SOCK

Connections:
+5V: C1.1, R1.2, R6.2, U2.6 (VS); also elsewhere on the board
/MCU_RUN1: R5.2; also elsewhere on the board
/MCU_RUN2: X2.P$21, X2.P$22; also elsewhere on the board
/MCU_RUN3: X2.P$17, X2.P$18; also elsewhere on the board
GATE_VOUT1: D1.2 (A), Q1.P$4 (G), R3.1, U1.COLLECTOR (COL)
GND: C1.2, R2.1, U2.1 (A1), U2.2 (A0), U2.7 (GND), U3.CATHODE (C), U3.EMITTER (EMIT), X1.P$1, X1.P$2, X1.P$3, X2.P$3_1, X2.P$3_2, X2.P$3_3, X2.P$4_1, X2.P$4_2, X2.P$4_3, X2.P$11, X2.P$12; also elsewhere on the board
KILL_SWITCH_C: U1.CATHODE (C); also elsewhere on the board
unnamed: R2.2, U1.EMITTER (EMIT)
unnamed: R5.1, U3.ANODE (A)
unnamed: R1.1, U1.ANODE (A)
PGOOD1: R6.1, X2.P$25, X2.P$26; also elsewhere on the board
PGOOD2: X2.P$19, X2.P$20; also elsewhere on the board
PGOOD3: X2.P$15, X2.P$16; also elsewhere on the board
RUN1: U3.COLLECTOR (COL), X2.P$23, X2.P$24
SCL: U2.5 (SCL), X2.P$27, X2.P$28; also elsewhere on the board
SDA: U2.4 (SDA), X2.P$29, X2.P$30; also elsewhere on the board
VIN: F1.P$1 (1), F1.P$2 (1); also elsewhere on the board
VIN1: F1.P$3 (2), F1.P$4 (2), X2.P$1_1, X2.P$1_2, X2.P$1_3, X2.P$2_1, X2.P$2_2, X2.P$2_3
VOUT1: D1.1 (C), Q1.P$1 (S), Q1.P$2 (S), Q1.P$3 (S), R3.2, R4.1, U2.8 (VBUS), U2.9 (IN-), X1.P$5, X1.P$6
VOUT_SENSE1: R4.2, U2.10 (IN+), X2.P$5_1, X2.P$5_2, X2.P$5_3, X2.P$6_1, X2.P$6_2, X2.P$6_3
VOUT_SWITCHED1: Q1.P$5 (D), Q1.P$6 (D), Q1.P$7 (D), Q1.P$8 (D), X1.P$4

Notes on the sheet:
NOTES: 1. INA226 address: 0b1000000

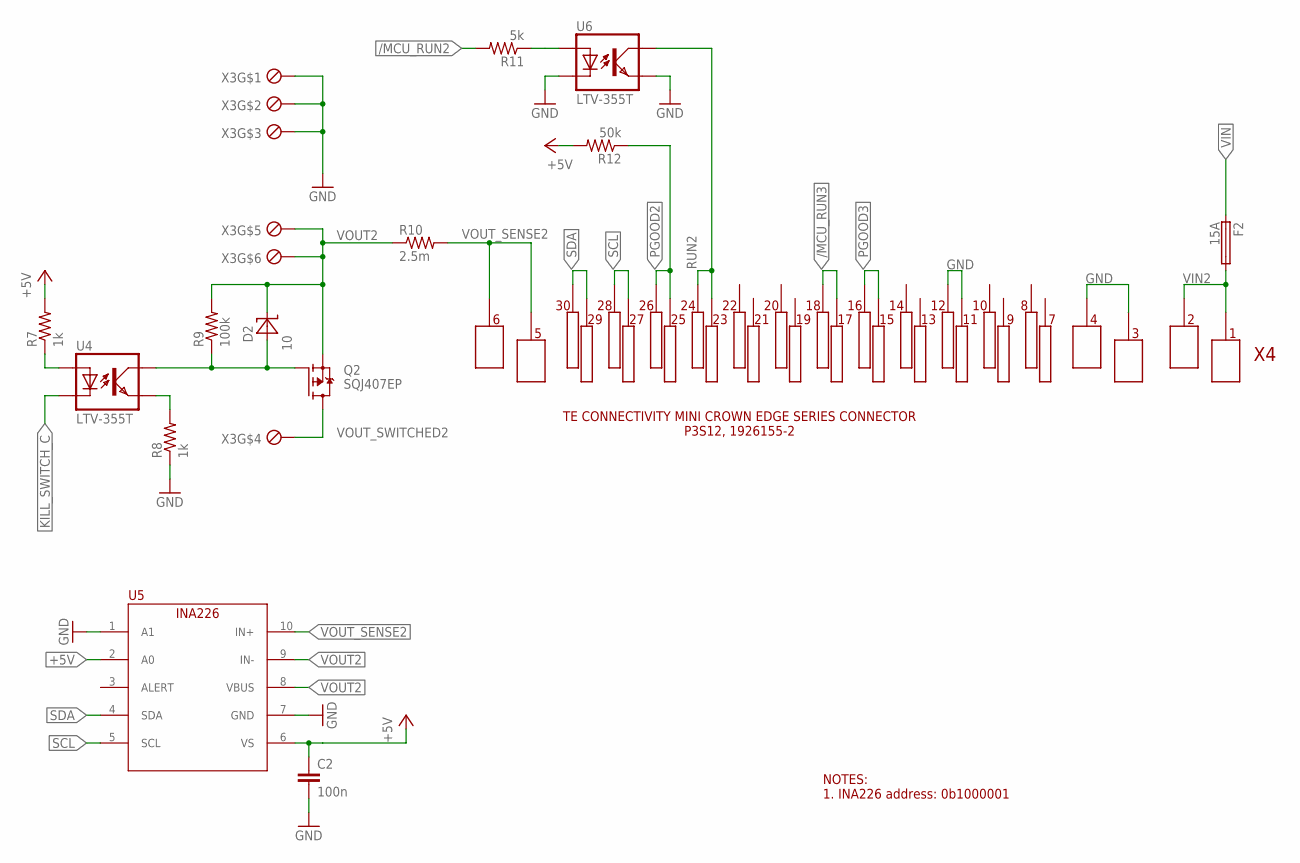
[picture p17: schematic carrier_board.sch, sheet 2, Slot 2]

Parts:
C2: 100n; C0603
D2: 10; SOD123
F2: 15A; 3557-10
Q2: SQJ407EP; POWERPAK_SO8L_SINGLE
R7, R8: 1k; R0603
R9: 100k; R0603
R10: 2.5m; R2512
R11: 5k; R0603
R12: 50k; R0603
U4, U6: LTV-355T; SMD4
U5: INA226; MSOP10
X3: 284391-6
X4: 1926155-2_SOCK

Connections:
+5V: C2.1, R7.2, R12.2, U5.2 (A0), U5.6 (VS); also elsewhere on the board
/MCU_RUN2: R11.2; also elsewhere on the board
/MCU_RUN3: X4.P$17, X4.P$18; also elsewhere on the board
GATE_VOUT2: D2.2 (A), Q2.P$4 (G), R9.1, U4.COLLECTOR (COL)
GND: C2.2, R8.1, U5.1 (A1), U5.7 (GND), U6.CATHODE (C), U6.EMITTER (EMIT), X3.P$1, X3.P$2, X3.P$3, X4.P$3_1, X4.P$3_2, X4.P$3_3, X4.P$4_1, X4.P$4_2, X4.P$4_3, X4.P$11, X4.P$12; also elsewhere on the board
KILL_SWITCH_C: U4.CATHODE (C); also elsewhere on the board
unnamed: R8.2, U4.EMITTER (EMIT)
unnamed: R7.1, U4.ANODE (A)
unnamed: R11.1, U6.ANODE (A)
PGOOD2: R12.1, X4.P$25, X4.P$26; also elsewhere on the board
PGOOD3: X4.P$15, X4.P$16; also elsewhere on the board
RUN2: U6.COLLECTOR (COL), X4.P$23, X4.P$24
SCL: U5.5 (SCL), X4.P$27, X4.P$28; also elsewhere on the board
SDA: U5.4 (SDA), X4.P$29, X4.P$30; also elsewhere on the board
VIN: F2.P$1 (1), F2.P$2 (1); also elsewhere on the board
VIN2: F2.P$3 (2), F2.P$4 (2), X4.P$1_1, X4.P$1_2, X4.P$1_3, X4.P$2_1, X4.P$2_2, X4.P$2_3
VOUT2: D2.1 (C), Q2.P$1 (S), Q2.P$2 (S), Q2.P$3 (S), R9.2, R10.1, U5.8 (VBUS), U5.9 (IN-), X3.P$5, X3.P$6
VOUT_SENSE2: R10.2, U5.10 (IN+), X4.P$5_1, X4.P$5_2, X4.P$5_3, X4.P$6_1, X4.P$6_2, X4.P$6_3
VOUT_SWITCHED2: Q2.P$5 (D), Q2.P$6 (D), Q2.P$7 (D), Q2.P$8 (D), X3.P$4

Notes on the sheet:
NOTES: 1. INA226 address: 0b1000001

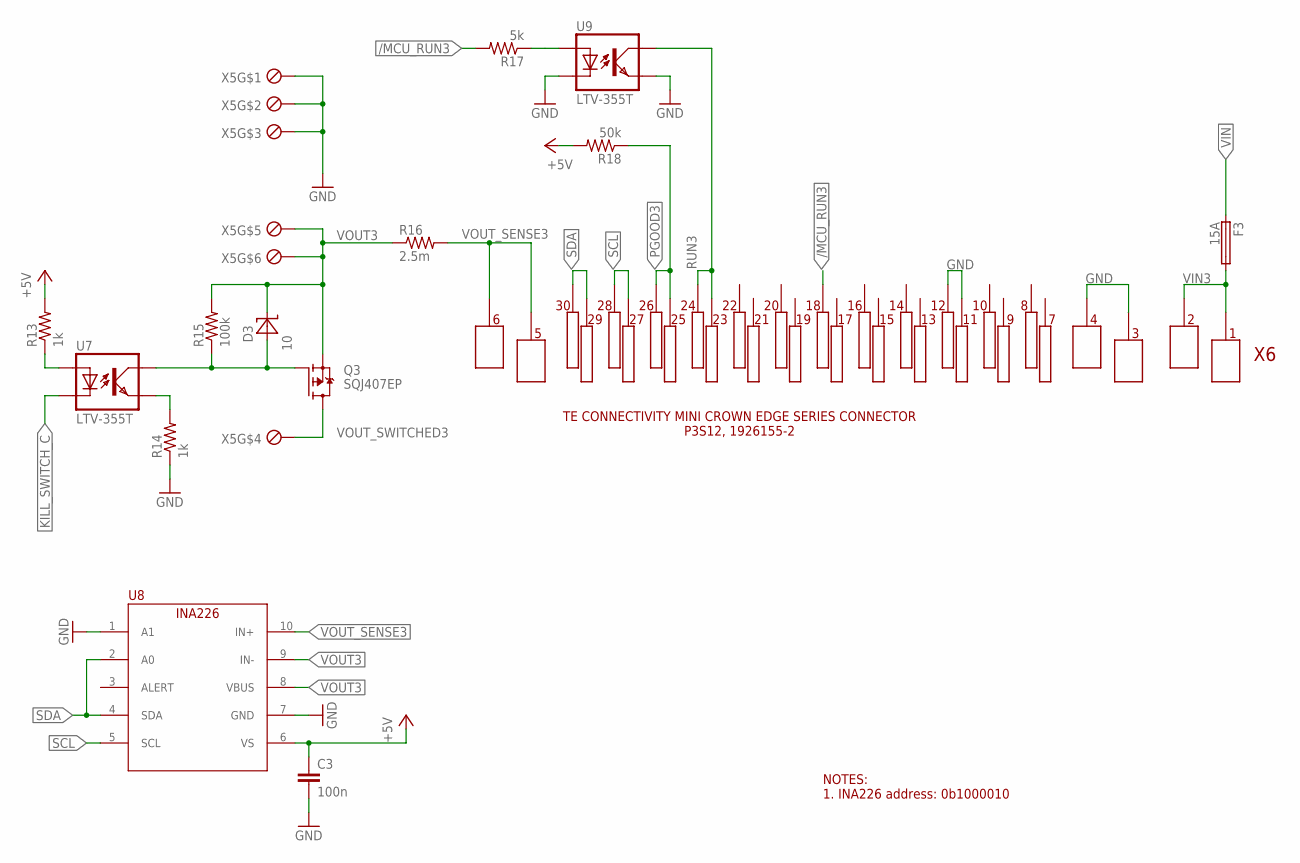
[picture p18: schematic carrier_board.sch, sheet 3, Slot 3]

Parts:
C3: 100n; C0603
D3: 10; SOD123
F3: 15A; 3557-10
Q3: SQJ407EP; POWERPAK_SO8L_SINGLE
R13, R14: 1k; R0603
R15: 100k; R0603
R16: 2.5m; R2512
R17: 5k; R0603
R18: 50k; R0603
U7, U9: LTV-355T; SMD4
U8: INA226; MSOP10
X5: 284391-6
X6: 1926155-2_SOCK

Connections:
+5V: C3.1, R13.2, R18.2, U8.6 (VS); also elsewhere on the board
/MCU_RUN3: R17.2, X6.P$18; also elsewhere on the board
GATE_VOUT3: D3.2 (A), Q3.P$4 (G), R15.1, U7.COLLECTOR (COL)
GND: C3.2, R14.1, U8.1 (A1), U8.7 (GND), U9.CATHODE (C), U9.EMITTER (EMIT), X5.P$1, X5.P$2, X5.P$3, X6.P$3_1, X6.P$3_2, X6.P$3_3, X6.P$4_1, X6.P$4_2, X6.P$4_3, X6.P$11, X6.P$12; also elsewhere on the board
KILL_SWITCH_C: U7.CATHODE (C); also elsewhere on the board
unnamed: R14.2, U7.EMITTER (EMIT)
unnamed: R13.1, U7.ANODE (A)
unnamed: R17.1, U9.ANODE (A)
PGOOD3: R18.1, X6.P$25, X6.P$26; also elsewhere on the board
RUN3: U9.COLLECTOR (COL), X6.P$23, X6.P$24
SCL: U8.5 (SCL), X6.P$27, X6.P$28; also elsewhere on the board
SDA: U8.2 (A0), U8.4 (SDA), X6.P$29, X6.P$30; also elsewhere on the board
VIN: F3.P$1 (1), F3.P$2 (1); also elsewhere on the board
VIN3: F3.P$3 (2), F3.P$4 (2), X6.P$1_1, X6.P$1_2, X6.P$1_3, X6.P$2_1, X6.P$2_2, X6.P$2_3
VOUT3: D3.1 (C), Q3.P$1 (S), Q3.P$2 (S), Q3.P$3 (S), R15.2, R16.1, U8.8 (VBUS), U8.9 (IN-), X5.P$5, X5.P$6
VOUT_SENSE3: R16.2, U8.10 (IN+), X6.P$5_1, X6.P$5_2, X6.P$5_3, X6.P$6_1, X6.P$6_2, X6.P$6_3
VOUT_SWITCHED3: Q3.P$5 (D), Q3.P$6 (D), Q3.P$7 (D), Q3.P$8 (D), X5.P$4

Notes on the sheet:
NOTES: 1. INA226 address: 0b1000010

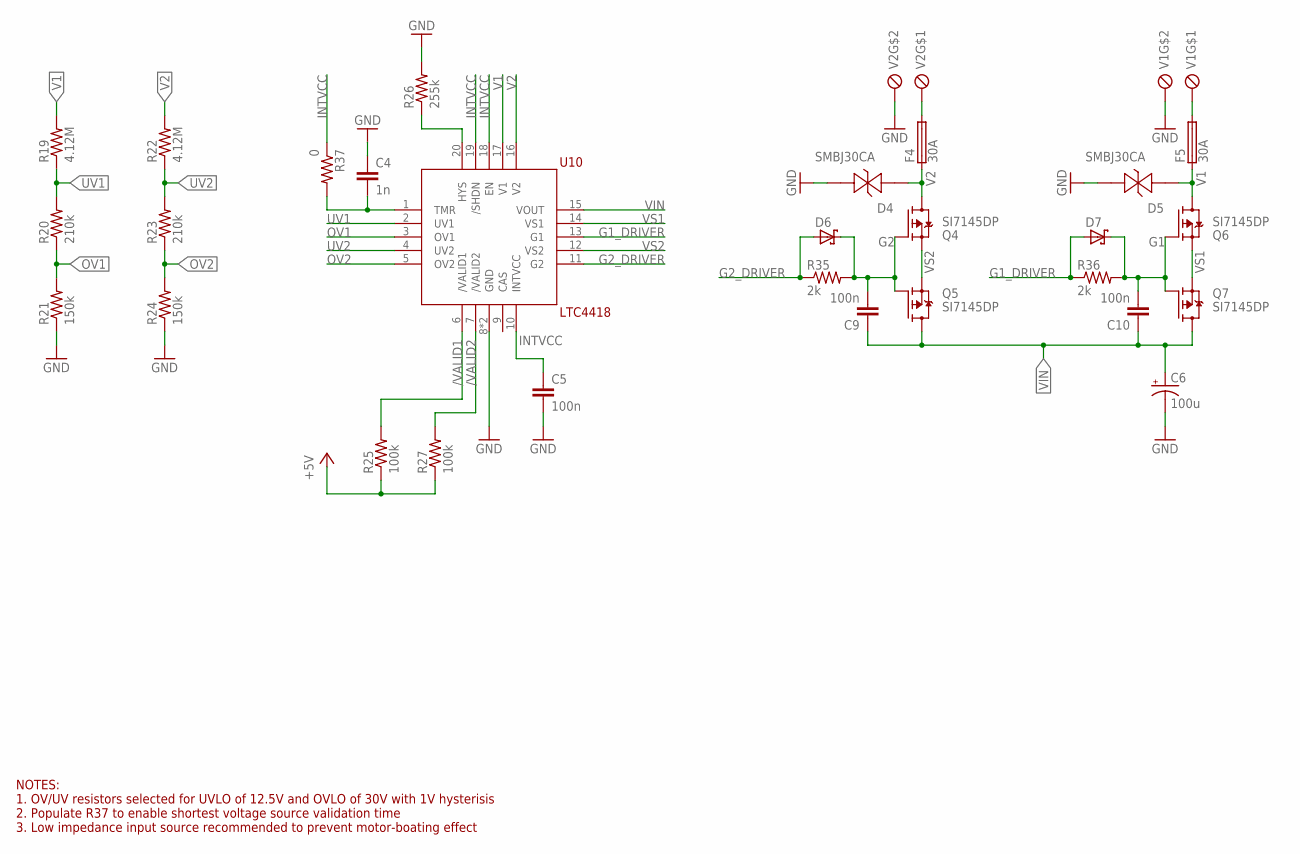
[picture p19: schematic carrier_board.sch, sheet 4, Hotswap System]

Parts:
C4: 1n; C0402
C5: 100n; C0402
C6: 100u; E5-10,5
C9, C10: 100n; C0603
D4, D5: SMBJ30CA; DO214AA
D6, D7: SD0603S040S0R2; CHIPLED_0603
F4, F5: 30A; 3557-10
Q4, Q5, Q6, Q7: SI7145DP; SO-8-POWERPAK
R19, R22: 4.12M; R0402
R20, R23: 210k; R0402
R21, R24: 150k; R0402
R25, R27: 100k; R0603
R26: 255k; R0402
R35, R36: 2k; R0603
R37: 0; R0402
U10: LTC4418; QFN20
V1, V2: MKDSD_1730502

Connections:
+5V: R25.1, R27.1; also elsewhere on the board
/VALID1: R25.2, U10.6 (/VALID1); also elsewhere on the board
/VALID2: R27.2, U10.7 (/VALID2); also elsewhere on the board
G1: C10.2, D7.C, Q6.4 (G), Q7.4 (G), R36.2
G1_DRIVER: D7.A, R36.1, U10.13 (G1)
G2: C9.2, D6.C, Q4.4 (G), Q5.4 (G), R35.2
G2_DRIVER: D6.A, R35.1, U10.11 (G2)
GND: C4.1, C5.2, C6.-, D4.A (2), D5.A (2), R21.1, R24.1, R26.2, U10.8 (GND), U10.EXP (GND), V1.P$2, V1.P$4, V2.P$2, V2.P$4; also elsewhere on the board
HYS: R26.1, U10.20 (HYS)
INTVCC: C5.1, R37.1, U10.10 (INTVCC), U10.18 (EN), U10.19 (/SHDN)
OV1: R20.1, R21.2, U10.3 (OV1)
OV2: R23.1, R24.2, U10.5 (OV2)
TMR: C4.2, R37.2, U10.1 (TMR)
UV1: R19.1, R20.2, U10.2 (UV1)
UV2: R22.1, R23.2, U10.4 (UV2)
V1: D5.C (1), F5.P$1 (1), F5.P$2 (1), Q6.5 (D), Q6.6 (D), Q6.7 (D), Q6.8 (D), Q6.P$1 (D), R19.2, U10.17 (V1)
V2: D4.C (1), F4.P$1 (1), F4.P$2 (1), Q4.5 (D), Q4.6 (D), Q4.7 (D), Q4.8 (D), Q4.P$1 (D), R22.2, U10.16 (V2)
VBAT1: F5.P$3 (2), F5.P$4 (2), V1.P$1, V1.P$3
VBAT2: F4.P$3 (2), F4.P$4 (2), V2.P$1, V2.P$3
VIN: C6.+, C9.1, C10.1, Q5.5 (D), Q5.6 (D), Q5.7 (D), Q5.8 (D), Q5.P$1 (D), Q7.5 (D), Q7.6 (D), Q7.7 (D), Q7.8 (D), Q7.P$1 (D), U10.15 (VOUT); also elsewhere on the board
VS1: Q6.1 (S), Q6.2 (S), Q6.3 (S), Q7.1 (S), Q7.2 (S), Q7.3 (S), U10.14 (VS1)
VS2: Q4.1 (S), Q4.2 (S), Q4.3 (S), Q5.1 (S), Q5.2 (S), Q5.3 (S), U10.12 (VS2)

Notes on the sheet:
NOTES: 1. OV/UV resistors selected for UVLO of 12.5V and OVLO of 30V with 1V hysterisis 2. Populate R37 to enable shortest voltage source validation time 3. Low impedance input source recommended to prevent motor-boating effect

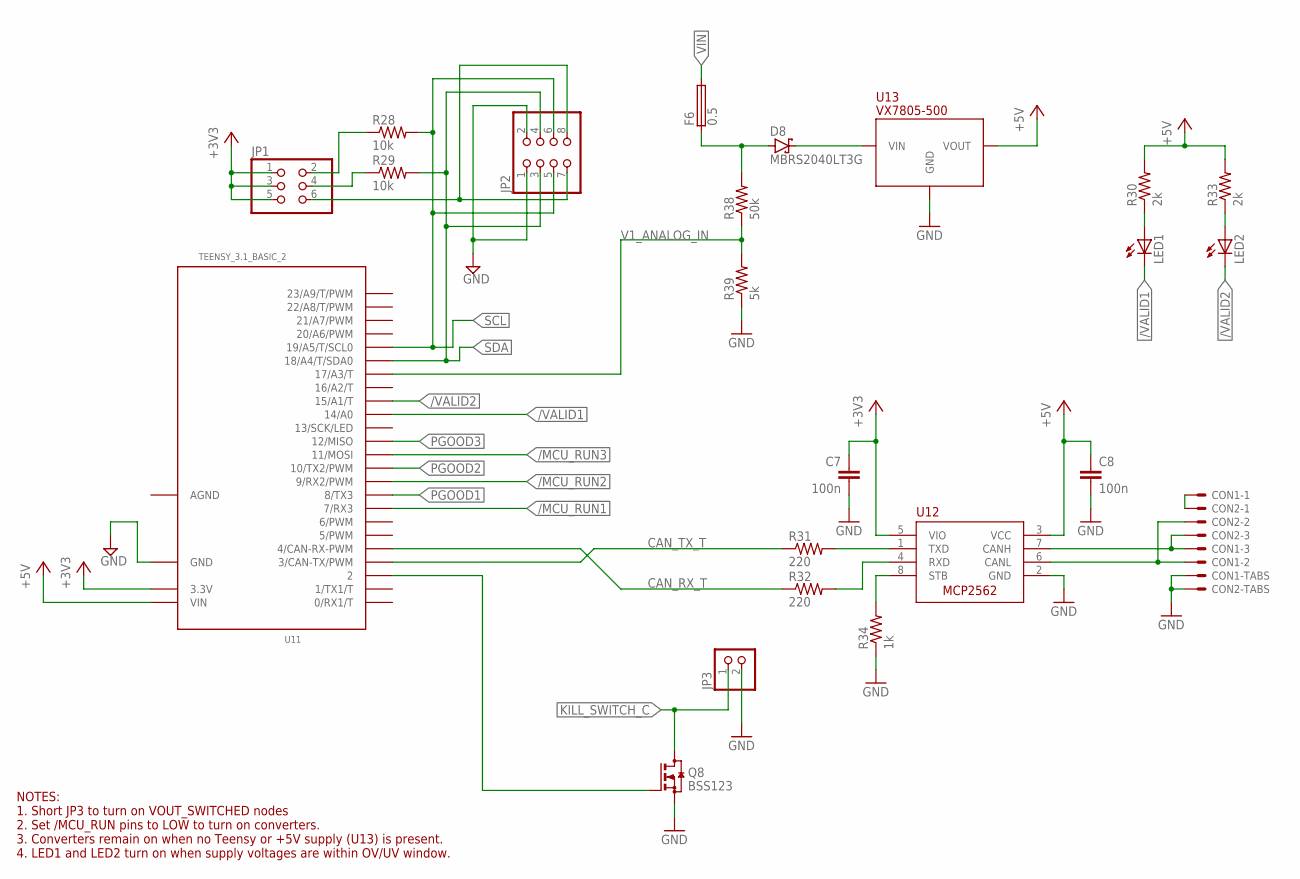
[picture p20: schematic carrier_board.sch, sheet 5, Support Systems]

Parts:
C7, C8: 100n; C0805
CON1, CON2: SM03B-GHS-TB
D8: MBRS2040LT3G; SMB
F6: 0.5; R1206
JP1: PINHD-2X3; 2X03
JP2: PINHD-2X4; 2X04
JP3: PINHD-1X02_2.54-SMD-90°; 1X02SMD/90
LED1, LED2: LEDCHIPLED_0603; CHIPLED_0603
Q8: BSS123; SOT23
R28, R29: 10k; R0805
R30, R33: 2k; R0603
R31, R32: 220; R0805
R34: 1k; R0805
R38: 50k; R0603
R39: 5k; R0603
U11: TEENSY_3.1_BASIC_2
U12: MCP2562; SO-8
U13: VX7805-500; 0.1"_LINEAR_REGULATOR_REPLACEMENT

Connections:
+3V3: C7.1, JP1.1, JP1.3, JP1.5, U11.3.3V, U12.5 (VIO)
+5V: C8.1, R30.2, R33.2, U11.VIN, U12.3 (VCC), U13.3 (VOUT); also elsewhere on the board
/MCU_RUN1: U11.7 (7/RX3); also elsewhere on the board
/MCU_RUN2: U11.9 (9/RX2/PWM); also elsewhere on the board
/MCU_RUN3: U11.11 (11/MOSI); also elsewhere on the board
/VALID1: LED1.C, U11.14/A0; also elsewhere on the board
/VALID2: LED2.C, U11.15/A1 (15/A1/T); also elsewhere on the board
AGND: U11.AGND
CANH: CON1.P$3, CON2.P$3, U12.7 (CANH)
CANL: CON1.P$2, CON2.P$2, U12.6 (CANL)
CANSH: CON1.P$1, CON2.P$1
CAN_RX: R32.2, U12.4 (RXD)
CAN_RX_T: R32.1, U11.4 (4/CAN-RX-PWM)
CAN_TX: R31.2, U12.1 (TXD)
CAN_TX_T: R31.1, U11.3 (3/CAN-TX/PWM)
GND: C7.2, C8.2, CON1.P$4, CON1.P$5, CON2.P$4, CON2.P$5, JP2.1, JP2.2, JP3.2, Q8.2 (S), R34.1, R39.1, U11.GND, U12.2 (GND), U13.2 (GND); also elsewhere on the board
I2C_3V3: JP1.6, JP2.7, JP2.8
KILL_SWITCH_C: JP3.1, Q8.3 (D); also elsewhere on the board
unnamed: D8.A, F6.1, R38.2
unnamed: LED1.A, R30.1
unnamed: LED2.A, R33.1
unnamed: Q8.1 (G), U11.2
unnamed: D8.C, U13.1 (VIN)
PGOOD1: U11.8 (8/TX3); also elsewhere on the board
PGOOD2: U11.10 (10/TX2/PWM); also elsewhere on the board
PGOOD3: U11.12 (12/MISO); also elsewhere on the board
SCL: JP2.5, JP2.6, R28.2, U11.19/A5 (19/A5/T/SCL0); also elsewhere on the board
SCL_3V3: JP1.2, R28.1
SDA: JP2.3, JP2.4, R29.2, U11.18/A4 (18/A4/T/SDA0); also elsewhere on the board
SDA_3V3: JP1.4, R29.1
STB: R34.2, U12.8 (STB)
V1_ANALOG_IN: R38.1, R39.2, U11.17/A3 (17/A3/T)
VIN: F6.2; also elsewhere on the board

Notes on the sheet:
NOTES: 1. Short JP3 to turn on VOUT_SWITCHED nodes 2. Set /MCU_RUN pins to LOW to turn on converters. 3. Converters remain on when no Teensy or +5V supply (U13) is present. 4. LED1 and LED2 turn on when supply voltages are within OV/UV window.

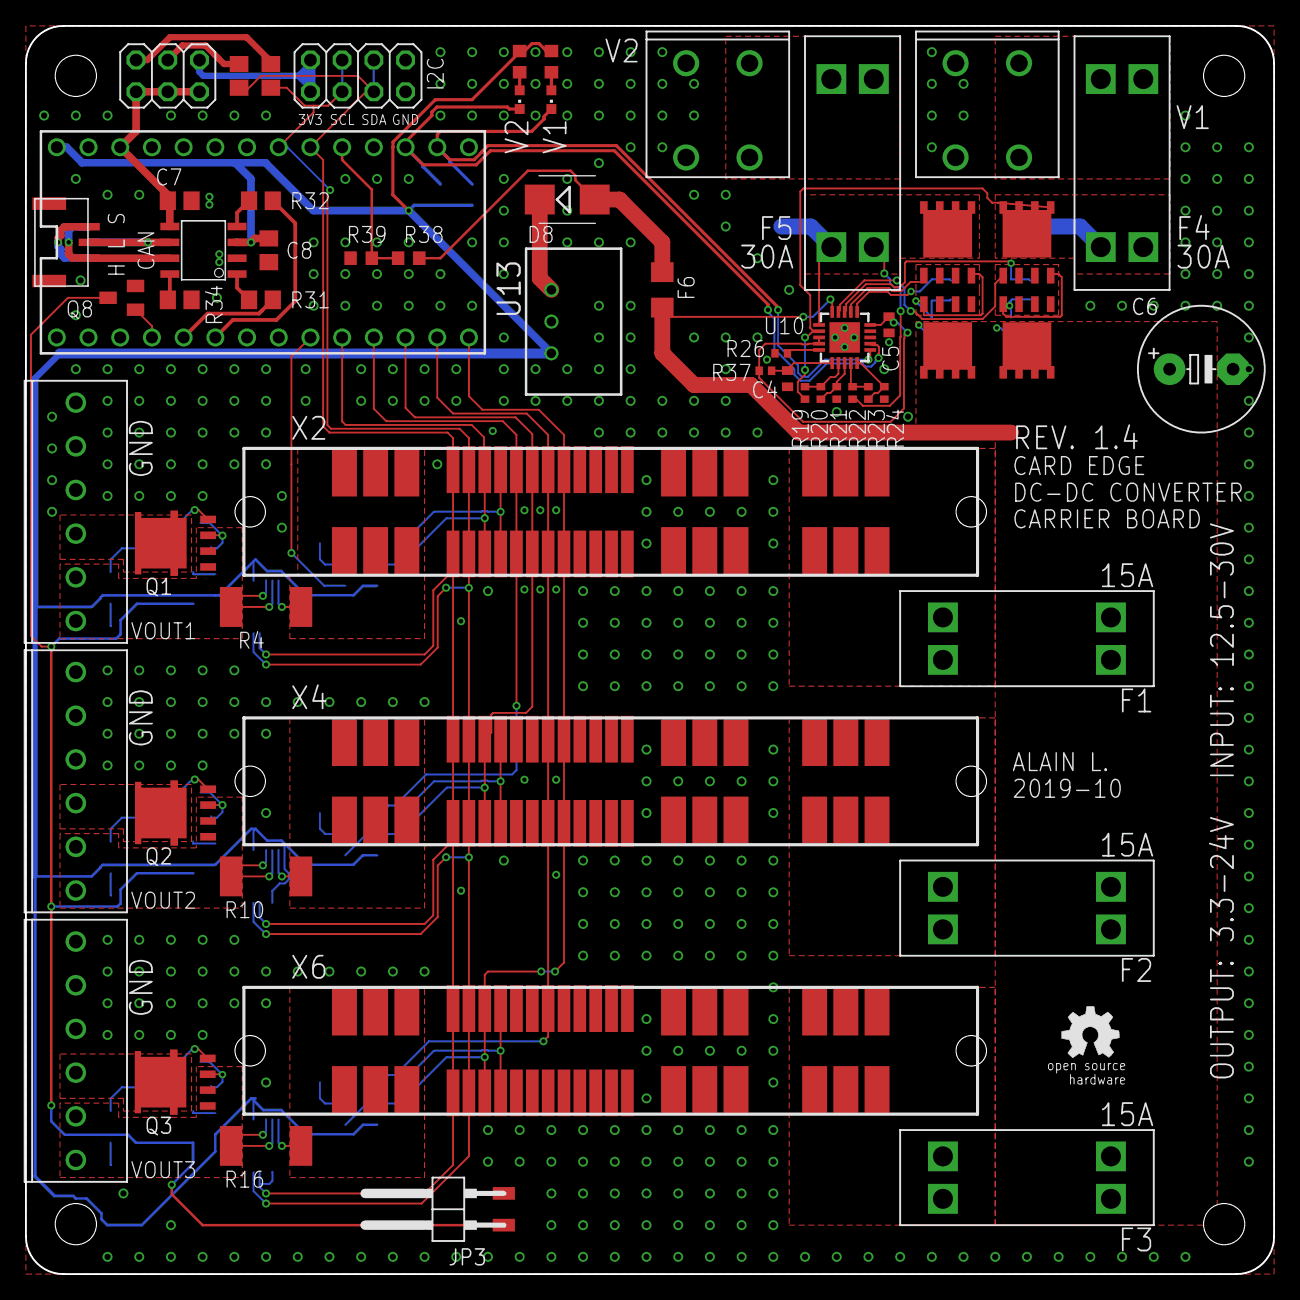
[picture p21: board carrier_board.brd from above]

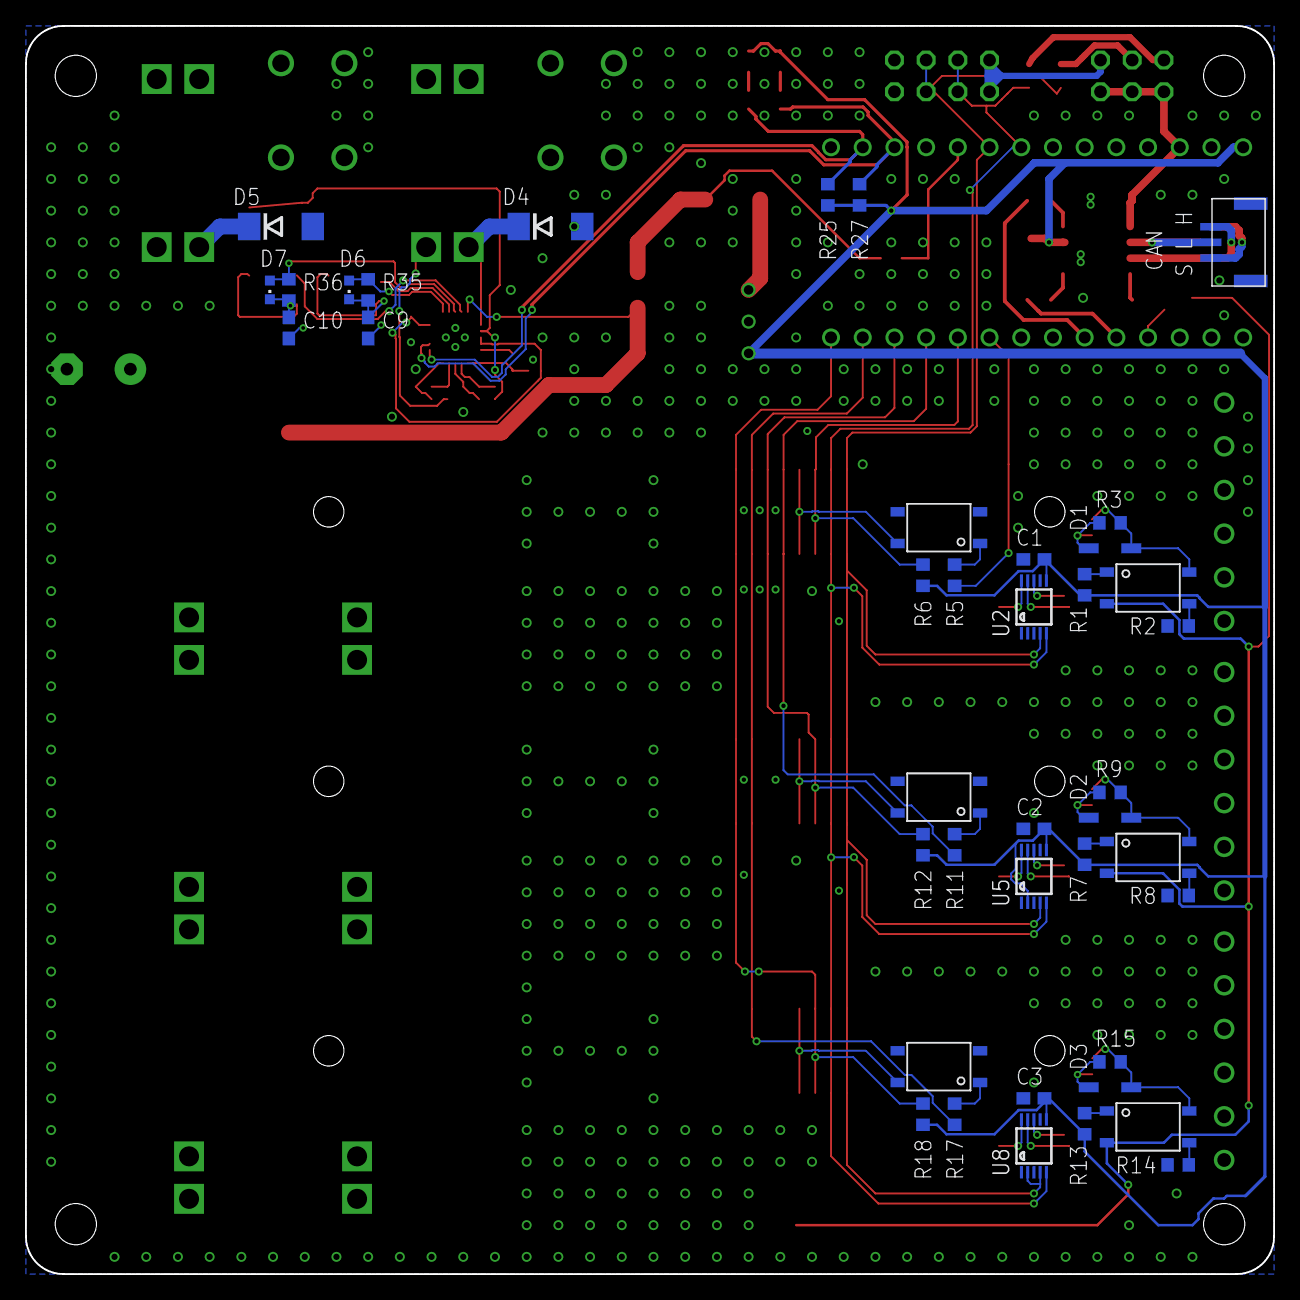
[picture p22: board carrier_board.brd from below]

Board: 2 copper layers, 100.0 x 100.0 mm, 105 parts (41 on the bottom side), 76 nets.

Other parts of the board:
U$1, U$2, U$3, U$4: STAND-OFF
U$5: A4L-LOC
U$7: OSHW_5MM

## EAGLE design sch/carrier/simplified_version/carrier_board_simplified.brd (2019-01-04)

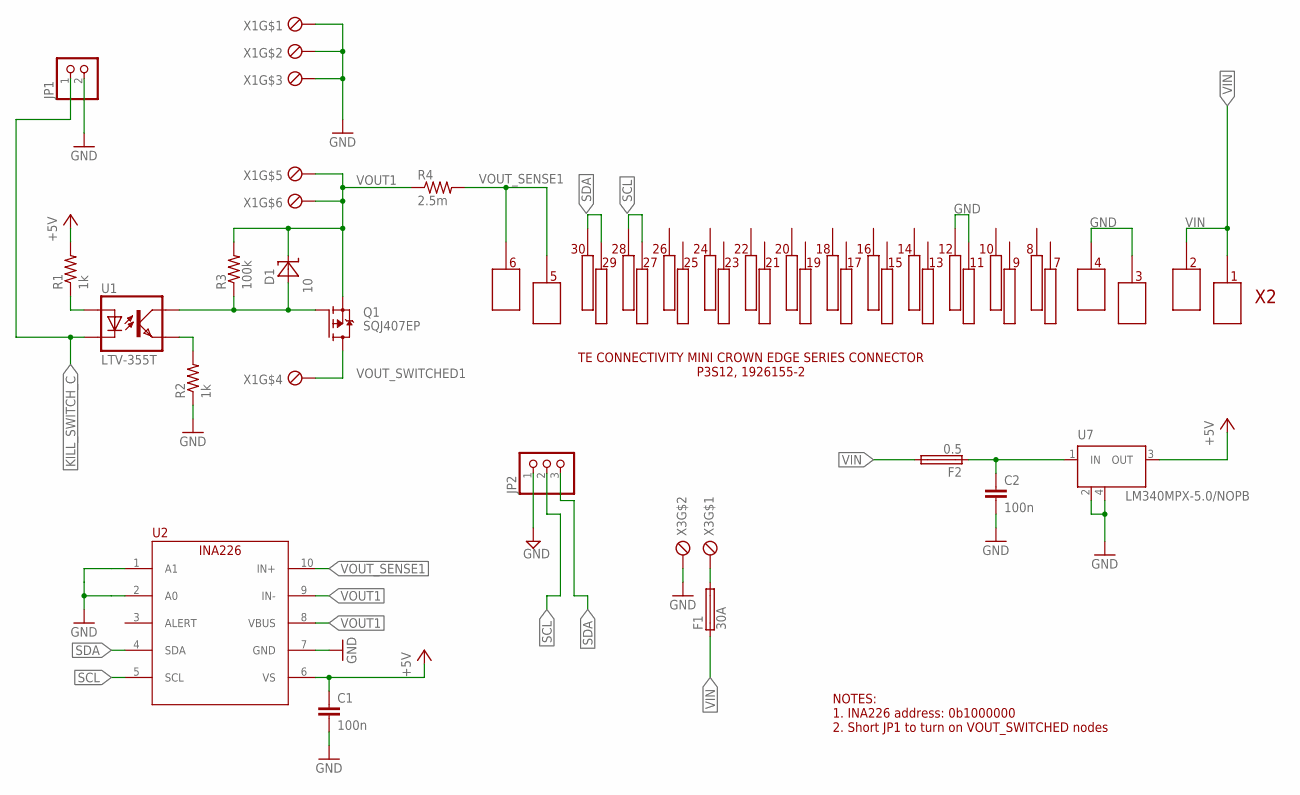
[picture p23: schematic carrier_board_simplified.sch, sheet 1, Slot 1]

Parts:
C1, C2: 100n; C0603
D1: 10; SOD123
F1: 30A; 3557-10
F2: 0.5; R1206
JP1: PINHD-1X02_2.54-SMD-90°; 1X02SMD/90
JP2: PINHD-1X03_2.54-SMD-90°; 1X03SMD/90
Q1: SQJ407EP; POWERPAK_SO8L_SINGLE
R1, R2: 1k; R0603
R3: 100k; R0603
R4: 2.5m; R2512
U1: LTV-355T; SMD4
U2: INA226; MSOP10
U7: LM340MPX-5.0/NOPB; SOT223
X1: 284391-6
X2: 1926155-2_SOCK
X3: OSTT7020150

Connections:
+5V: C1.1, R1.2, U2.6 (VS), U7.3 (OUT); also elsewhere on the board
GATE_VOUT1: D1.2 (A), Q1.P$4 (G), R3.1, U1.COLLECTOR (COL)
GND: C1.2, C2.2, JP1.2, JP2.1, R2.1, U2.1 (A1), U2.2 (A0), U2.7 (GND), U7.2 (GND), U7.4 (GND), X1.P$1, X1.P$2, X1.P$3, X2.P$3_1, X2.P$3_2, X2.P$3_3, X2.P$4_1, X2.P$4_2, X2.P$4_3, X2.P$11, X2.P$12, X3.2; also elsewhere on the board
KILL_SWITCH_C: JP1.1, U1.CATHODE (C); also elsewhere on the board
unnamed: C2.1, F2.1, U7.1 (IN)
unnamed: R2.2, U1.EMITTER (EMIT)
unnamed: R1.1, U1.ANODE (A)
SCL: JP2.2, U2.5 (SCL), X2.P$27, X2.P$28; also elsewhere on the board
SDA: JP2.3, U2.4 (SDA), X2.P$29, X2.P$30; also elsewhere on the board
VBAT1: F1.P$3 (2), F1.P$4 (2), X3.1
VIN: F1.P$1 (1), F1.P$2 (1), F2.2, X2.P$1_1, X2.P$1_2, X2.P$1_3, X2.P$2_1, X2.P$2_2, X2.P$2_3; also elsewhere on the board
VOUT1: D1.1 (C), Q1.P$1 (S), Q1.P$2 (S), Q1.P$3 (S), R3.2, R4.1, U2.8 (VBUS), U2.9 (IN-), X1.P$5, X1.P$6
VOUT_SENSE1: R4.2, U2.10 (IN+), X2.P$5_1, X2.P$5_2, X2.P$5_3, X2.P$6_1, X2.P$6_2, X2.P$6_3
VOUT_SWITCHED1: Q1.P$5 (D), Q1.P$6 (D), Q1.P$7 (D), Q1.P$8 (D), X1.P$4

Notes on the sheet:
NOTES: 1. INA226 address: 0b1000000 2. Short JP1 to turn on VOUT_SWITCHED nodes

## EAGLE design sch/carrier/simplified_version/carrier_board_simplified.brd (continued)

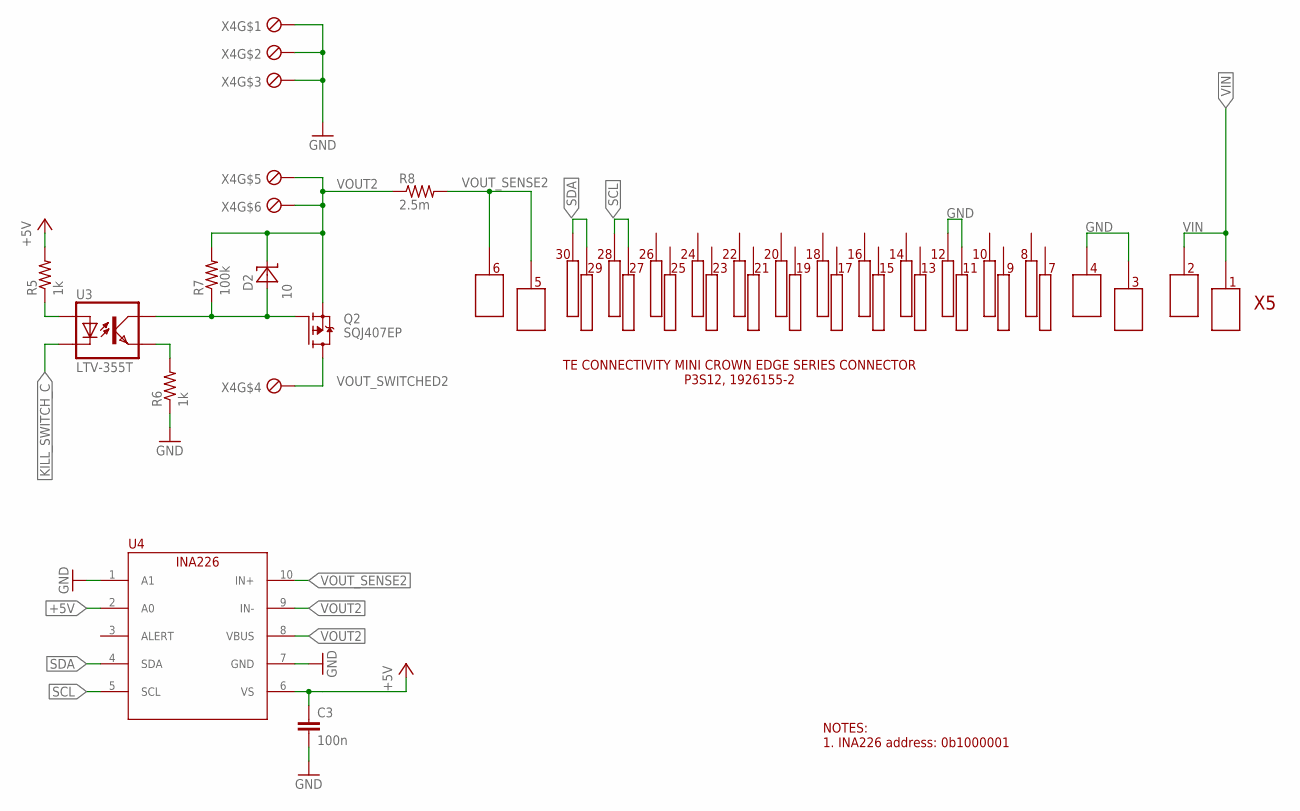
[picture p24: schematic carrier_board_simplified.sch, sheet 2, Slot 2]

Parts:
C3: 100n; C0603
D2: 10; SOD123
Q2: SQJ407EP; POWERPAK_SO8L_SINGLE
R5, R6: 1k; R0603
R7: 100k; R0603
R8: 2.5m; R2512
U3: LTV-355T; SMD4
U4: INA226; MSOP10
X4: 284391-6
X5: 1926155-2_SOCK

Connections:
+5V: C3.1, R5.2, U4.2 (A0), U4.6 (VS); also elsewhere on the board
GATE_VOUT2: D2.2 (A), Q2.P$4 (G), R7.1, U3.COLLECTOR (COL)
GND: C3.2, R6.1, U4.1 (A1), U4.7 (GND), X4.P$1, X4.P$2, X4.P$3, X5.P$3_1, X5.P$3_2, X5.P$3_3, X5.P$4_1, X5.P$4_2, X5.P$4_3, X5.P$11, X5.P$12; also elsewhere on the board
KILL_SWITCH_C: U3.CATHODE (C); also elsewhere on the board
unnamed: R6.2, U3.EMITTER (EMIT)
unnamed: R5.1, U3.ANODE (A)
SCL: U4.5 (SCL), X5.P$27, X5.P$28; also elsewhere on the board
SDA: U4.4 (SDA), X5.P$29, X5.P$30; also elsewhere on the board
VIN: X5.P$1_1, X5.P$1_2, X5.P$1_3, X5.P$2_1, X5.P$2_2, X5.P$2_3; also elsewhere on the board
VOUT2: D2.1 (C), Q2.P$1 (S), Q2.P$2 (S), Q2.P$3 (S), R7.2, R8.1, U4.8 (VBUS), U4.9 (IN-), X4.P$5, X4.P$6
VOUT_SENSE2: R8.2, U4.10 (IN+), X5.P$5_1, X5.P$5_2, X5.P$5_3, X5.P$6_1, X5.P$6_2, X5.P$6_3
VOUT_SWITCHED2: Q2.P$5 (D), Q2.P$6 (D), Q2.P$7 (D), Q2.P$8 (D), X4.P$4

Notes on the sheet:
NOTES: 1. INA226 address: 0b1000001


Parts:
C4: 100n; C0603
D3: 10; SOD123
Q3: SQJ407EP; POWERPAK_SO8L_SINGLE
R9, R10: 1k; R0603
R11: 100k; R0603
R12: 2.5m; R2512
U5: LTV-355T; SMD4
U6: INA226; MSOP10
X6: 284391-6
X7: 1926155-2_SOCK

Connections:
+5V: C4.1, R9.2, U6.6 (VS); also elsewhere on the board
GATE_VOUT3: D3.2 (A), Q3.P$4 (G), R11.1, U5.COLLECTOR (COL)
GND: C4.2, R10.1, U6.1 (A1), U6.7 (GND), X6.P$1, X6.P$2, X6.P$3, X7.P$3_1, X7.P$3_2, X7.P$3_3, X7.P$4_1, X7.P$4_2, X7.P$4_3, X7.P$11, X7.P$12; also elsewhere on the board
KILL_SWITCH_C: U5.CATHODE (C); also elsewhere on the board
unnamed: R10.2, U5.EMITTER (EMIT)
unnamed: R9.1, U5.ANODE (A)
SCL: U6.5 (SCL), X7.P$27, X7.P$28; also elsewhere on the board
SDA: U6.2 (A0), U6.4 (SDA), X7.P$29, X7.P$30; also elsewhere on the board
VIN: X7.P$1_1, X7.P$1_2, X7.P$1_3, X7.P$2_1, X7.P$2_2, X7.P$2_3; also elsewhere on the board
VOUT3: D3.1 (C), Q3.P$1 (S), Q3.P$2 (S), Q3.P$3 (S), R11.2, R12.1, U6.8 (VBUS), U6.9 (IN-), X6.P$5, X6.P$6
VOUT_SENSE3: R12.2, U6.10 (IN+), X7.P$5_1, X7.P$5_2, X7.P$5_3, X7.P$6_1, X7.P$6_2, X7.P$6_3
VOUT_SWITCHED3: Q3.P$5 (D), Q3.P$6 (D), Q3.P$7 (D), Q3.P$8 (D), X6.P$4

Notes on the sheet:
NOTES: 1. INA226 address: 0b1000010



Board: 2 copper layers, 100.0 x 79.0 mm, 45 parts (21 on the bottom side), 26 nets.

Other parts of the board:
U$1, U$2, U$3, U$4: STAND-OFF
U$5: A4L-LOC

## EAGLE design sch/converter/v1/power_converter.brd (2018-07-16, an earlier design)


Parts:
C1, C2, C3, C4, C5, C6, C8, C9, C10, C11, C12, C13: 10u; C1210
C7: 180u; PCR1H181MCL1GS
C14, C15: 220u; PCR1V221MCL1GS
C16: 5n; C0603
D1: 4.7V; SOT23
JP1, JP2: PINHD-1X02_2.54-SMD; 1X02SMD
L1: 4.7u; 74439370047
PAD1, PAD2, PAD3, PAD4, PAD5, PAD6, PAD7, PAD8: 3,81/1,5
R1: 51k; R0603
R2: 100k; R0603
R3: 8.5k; R0603
R4, R5: 15m; R1206
R6: 4.7k; R0603
R7: 150; R0603
R8: 6.98k; R0603
R9: 2.7k; R0603
U1: LTM4607EVPBF; LGA-141

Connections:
COMP: U1.B7 (COMP)
EXTVCC: U1.F6 (EXTVCC)
GND: C1.2, C2.2, C3.2, C4.2, C5.2, C6.2, C7.NEG (-), C8.2, C9.2, C10.2, C11.2, C12.2, C13.2, C14.NEG (-), C15.NEG (-), C16.1, D1.1 (A), JP2.2, PAD5.1, PAD6.1, PAD7.1, PAD8.1, R3.1, R4.2, R5.2, R8.1, R9.2, U1.A1 (PGND), U1.A2 (PGND), U1.A3 (PGND), U1.A5 (SENSE-), U1.A7 (SGND), U1.A9 (FCB), U1.A11 (PGND), U1.A12 (PGND), U1.B1 (PGND), U1.B2 (PGND), U1.B3 (PGND), U1.B4 (PGND), U1.B10 (PGND), U1.B11 (PGND), U1.B12 (PGND), U1.C1 (PGND), U1.C2 (PGND), U1.C3 (PGND), U1.C4 (PGND), U1.C5 (PGND), U1.C6 (PGND), U1.C7 (PGND), U1.C8 (PGND), U1.C9 (PGND), U1.C10 (PGND), U1.C11 (PGND), U1.C12 (PGND), U1.D1 (PGND), U1.D2 (PGND), U1.D3 (PGND), U1.D4 (PGND), U1.D5 (PGND), U1.D6 (PGND), U1.D7 (PGND), U1.D8 (PGND), U1.D9 (PGND), U1.D10 (PGND), U1.D11 (PGND), U1.D12 (PGND), U1.E3 (PGND), U1.E4 (PGND), U1.E5 (PGND), U1.E6 (PGND), U1.E7 (PGND), U1.E8 (PGND), U1.E9 (PGND), U1.E10 (PGND), U1.E11 (PGND), U1.E12 (PGND)
INTVCC: R2.1, R6.2, U1.F5 (INTVCC)
unnamed: R7.1, R8.2
unnamed: JP1.2, R1.1, R3.2
PGOOD: JP2.1, R2.2, U1.B5 (PGOOD)
PLLFLTR: R6.1, R9.1, U1.B8 (PLLFLTR)
PLLIN: U1.B9 (PLLIN)
RSENSE: R4.1, R5.1, U1.A4 (SENSE+), U1.F10 (RSENSE), U1.F11 (RSENSE), U1.F12 (RSENSE), U1.G5 (RSENSE), U1.G6 (RSENSE), U1.G7 (RSENSE), U1.G8 (RSENSE), U1.G9 (RSENSE), U1.G10 (RSENSE), U1.G11 (RSENSE), U1.G12 (RSENSE), U1.H5 (RSENSE), U1.H6 (RSENSE), U1.H7 (RSENSE), U1.H8 (RSENSE), U1.H9 (RSENSE), U1.H10 (RSENSE), U1.H11 (RSENSE), U1.H12 (RSENSE), U1.J5 (RSENSE), U1.J6 (RSENSE), U1.J7 (RSENSE), U1.K5 (RSENSE), U1.K6 (RSENSE), U1.L5 (RSENSE), U1.L6 (RSENSE), U1.M5 (RSENSE), U1.M6 (RSENSE)
RUN: D1.3 (C), JP1.1, U1.A8 (RUN), U1.A10 (STBMD)
SS: C16.2, U1.A6 (SS)
SW1: L1.M2 (2), U1.J1 (SW1), U1.J2 (SW1), U1.J3 (SW1), U1.J4 (SW1), U1.K1 (SW1), U1.K2 (SW1), U1.K3 (SW1), U1.K4 (SW1), U1.L1 (SW1), U1.L2 (SW1), U1.L3 (SW1), U1.L4 (SW1), U1.M1 (SW1), U1.M2 (SW1), U1.M3 (SW1), U1.M4 (SW1)
SW2: L1.M1 (1), U1.J8 (SW2), U1.J9 (SW2), U1.K7 (SW2), U1.K8 (SW2), U1.K9 (SW2), U1.L7 (SW2), U1.L8 (SW2), U1.L9 (SW2), U1.M7 (SW2), U1.M8 (SW2), U1.M9 (SW2)
VFB: R7.2, U1.B6 (VFB)
VIN: C1.1, C2.1, C3.1, C4.1, C5.1, C6.1, C7.POS (+), PAD1.1, PAD2.1, R1.2, U1.J10 (VIN), U1.J11 (VIN), U1.J12 (VIN), U1.K10 (VIN), U1.K11 (VIN), U1.K12 (VIN), U1.L10 (VIN), U1.L11 (VIN), U1.L12 (VIN), U1.M10 (VIN), U1.M11 (VIN), U1.M12 (VIN)
VOUT: C8.1, C9.1, C10.1, C11.1, C12.1, C13.1, C14.POS (+), C15.POS (+), PAD3.1, PAD4.1, U1.E1 (VOUT), U1.E2 (VOUT), U1.F1 (VOUT), U1.F2 (VOUT), U1.F3 (VOUT), U1.F4 (VOUT), U1.G1 (VOUT), U1.G2 (VOUT), U1.G3 (VOUT), U1.G4 (VOUT), U1.H1 (VOUT), U1.H2 (VOUT), U1.H3 (VOUT), U1.H4 (VOUT)

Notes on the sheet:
Ceramic input/output caps: C3225X5R1H106K250AB
Al polymer input caps: PCR1H181MCL1GS
Al polymer output caps: PCR1V221MCL1GS
Two resistors can be used to set output voltage precisely. Selected values are for 12V output.
VOUT=0.8*(100K+R7+R8)/(R7+R8)
V_UVLO=1.6*(R1+R3)/R3. R3 design value set higher than calculation to make 12V lock-out work in LTSpice simulation.
Short JP1 to turn on converter.
R6-R9 divider sets switching frequency to 400kHz.
PGOOD is an open drain pin that is pulled to ground when output is not within 10% of regulation point. Rises to INTVCC(6V) otherwise.
Examples (Rfb = R7+R8) 3.3V: Rfb = 32.4k 5V: Rfb = 19.1k 6V: Rfb = 15.4k 9V: Rfb = 9.76k 12V: Rfb = 7.15k 15V: Rfb = 5.62k 24V: Rfb = 3.4k
Ratings: Input voltage: 4.5V-36V Output voltage: 0.8V-24V Output current: 5A in Boost mode (Vin<Vout) 10A in Buck mode (Vin>Vout)
Optocouplers recommeded for interfacing with micro-controllers
Inductor: 74439370047
Rev: 1.2



Board: 4 copper layers, 49.5 x 49.5 mm, 43 parts (8 on the bottom side), 14 nets.

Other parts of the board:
U$1, U$2, U$3, U$4: STAND-OFF
U$5: A4L-LOC

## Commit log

2018-04-21 Laid out and routed power components
    [power_converter.brd, power_converter.sch]
2018-04-26 Completed revision 1.0
    [power_converter.brd, power_converter.sch]
2018-04-26 Split current sense resistor into two; Added BOM and LTSpice simulation
    [power_converter.brd, power_converter.sch, power_converter_BOM.xlsx]
2018-04-26 Added CAM files; Increased wirepad drill; Added more vias
    [power_converter.brd, power_converter.sch]
2018-05-09 fixed typo in .sch
    [power_converter.sch]
2018-05-10 Reduced stencil hole size for LTM4607 to reduce odds of solder bridging
    [power_converter.brd, power_converter.sch]
2018-07-16 Restructured files
    [power_converter.brd, power_converter.sch, power_converter_BOM.xlsx]
2018-09-27 Version 2
    [power_converter.brd, power_converter.sch]
2018-10-06 Carrier board
    [carrier_board.brd, carrier_board.sch, power_converter.brd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]
2018-10-06 Updated pdf
    [carrier_board.brd]
2018-10-06 added simulation
    [carrier_board.brd]
2018-10-28 Added carrier BOM; Chaned carrier MOSFETs
    [carrier_board.brd, carrier_board.sch, carrier_board_BOM.xlsx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]
2018-10-28 Added CAM files
    [carrier_board.brd]
2018-10-28 Updated CAM files
    [carrier_board.brd, carrier_board.sch, power_converter.brd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]
2018-12-09 Revision 1.2
    [carrier_board.brd, carrier_board.sch, carrier_board_BOM.xlsx]
2018-12-15 Carrier rev. 1.3
    [carrier_board.brd, carrier_board.sch, carrier_board_BOM.xlsx]
2018-12-27 Fixed typo in sch
    [carrier_board.sch]
2018-12-27 Added missing via
    [carrier_board.brd]
2019-01-04 Simplified low-cost version 1.3-1 added
    [carrier_board_simplified.brd, carrier_board_simplified.sch, carrier_board_simplified.xlsx]
2019-10-14 Carrier rev. 1.4
    [carrier_board.brd, carrier_board.sch, carrier_board_BOM.xlsx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]
